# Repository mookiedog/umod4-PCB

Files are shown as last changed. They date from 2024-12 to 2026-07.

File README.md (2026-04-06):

# umod4-PCB

The Ultramod4 (A.K.A [umod4](https://github.com/mookiedog/umod4)) project is a real-time datalogger for Aprila Gen 1 ECUs.
It replaces the EPROM in an Aprila Gen 1 ECU with a circuit board that replaces the EPROM with a fast CPU that emulates an EPROM.
The EPROM emulation CPU's flash contains a special data logging firmware that the ECU will run.
The data-logging firmware is modified to send a real-time stream of ECU data to an interface on the umod4-PCB.
Software running in a daughterboard on the umod4-PCB combines the incoming ECU data stream with real-time GPS location and velocity information.
The combined data stream gets written to a logfile on a micro SD card.

The complete project is made up of:

* [umod4](https://github.com/mookiedog/umod4): the repository containing all the software that runs on the umod4-PCB.
* [UM4](https://github.com/mookiedog/umod4/tree/main/ecu/src): a special data logging firmware that runs inside the Gen1 ECU, currently resides inside the umod4 repository
* umod4-PCB: this repository, containing the PCB design files

The view below shows a top view of the 4V1a PCB, currently the most recent design.
The board's strange shape and cutout are mostly required to access ECU mounting points while avoiding interference with tall components on the ECU itself.
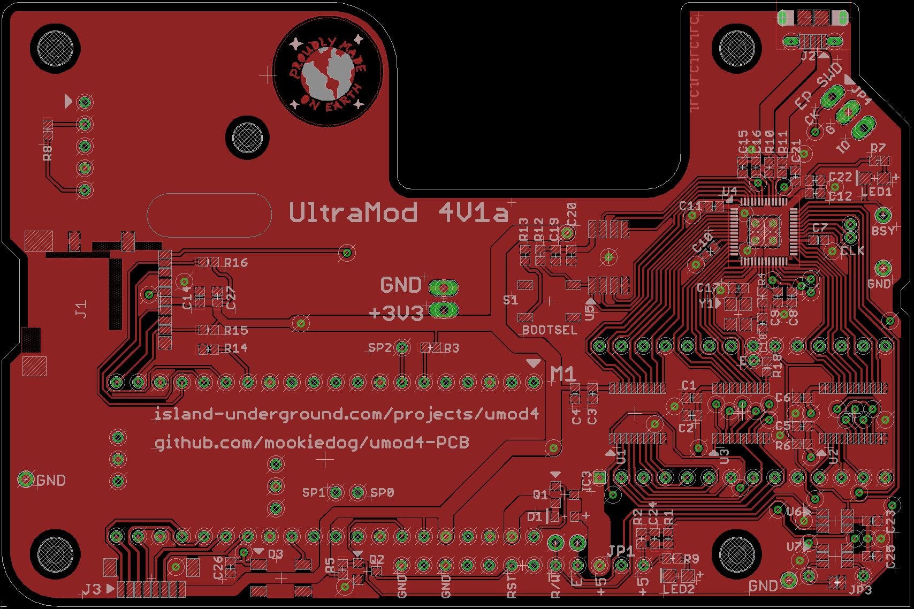
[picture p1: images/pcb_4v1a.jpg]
Ultramod 4V1a PCB layout


## PCB Status

The first version of the board (marked '4V0b' on its silkscreen) was fabricated at JCLPCB in 2022 and tested.
The second revision, the 4V1a board, was produced by JLCPCB in Jan 2025.
It incorporates all the workarounds from 4V0b, plus a number of changes and enhancements discovered over the last 18 months.
See the file [ChangeList.md](ChangeList.md) for the complete set of changes incorporated by 4V1.

The 4V1 version PCB has passed all its tests so far.

## Goals

### Design For Manufacture

This project uses a bare RP2040 chip to emulate the EPROM in a Gen 1 ECU.
The chip is too difficult for me to place by hand for reflowing the board using my [home-brew reflow](https://github.com/mookiedog/Reflow) process.
Instead, this PCB is designed for fabrication at JLCPCB.com.
Where possible, the BOM parts were chosen from JLCPCB's "basic" component list to avoid the fee for using an "extended" component.
Even so, stocks of "basic" parts fluctuate and components become obsolete, so the BOM might change with time to accomodate those changes.

Once any requirement for hand assembly was eliminated, the door was open to use smaller 0402 components on the PCB.

The initial version of the design (4V0b) has proven it can go end-to-end through the entire JCLPCB fabrication process where the resulting boards function as designed.

### Accessibility

I am not interested in making this project into a product that I would sell and support.
That said, it may be interesting enough for other Aprilia owners out there who have software and/or hardware skills that they might want to replicate the project for their own bike.

Who knows, it might be one of those things where a batch of boards gets made from time to time for people who are interested, feel like participating, and know that it is not a product.
Seriously, the last thing on earth that I want is someone sending me a note complaining that I haven't got WiFi working yet.

## Design Tool Choice

The project is currently developed using Cadsoft Eagle version 7.6, the last version I got years ago.
It's because I've used Eagle for the last bazillion years, and I own that old version outright.
These days, you are forced to forced to buy new versions of Eagle on a monthly subscription basis.
That doesn't work for me, because I make no money off this stuff and can't afford the subscription fees.
Too bad, I like Eagle.

I realize that at some point it would be worth switching the design over to something like KiCad to make it more accessible to the open source community.

Someday.

## Project Status

A ton of software exists, and a ton is left to write.

That said, the key to going for a ride though is that the fake EPROM on the circuit board needs to work. And it does!

Below, is a scope shot of the ECU performing memory cycles.
The top trace is the E clock generated by the ECU processor (a MC68HC11 variant).
The bottom trace is generated by the firmware that is pretending to be an EPROM.
The bottom trace goes high when the fake EPROM firmware reads the address and control signals from the HC11 memory bus.

If the memory cycle does not target the EPROM, the firmware drives the lower trace back to zero again very shortly after reading the address and control signal info.

If the memory cycle targets the EPROM with a read operation, the firmware takes a bit more time to access the proper memory byte corresponding to the desired EPROM memory byte, then drive that data onto the memory bus.
The lower scope trace gets driven low again to indicate the time that the read data is available on the memory bus.

Finally, if the memory cycle targets the EPROM with a write, the firmware is required to wait even longer for the write data to finally appear on the bus.
The fake EPROM firmware drives the lower trace back to zero to indicate the exact time that it samples the write data off the HC11 memory bus.

Given that all of these operations are going on all the time, the lower trace has been set up so that it shows examples of the three different operations (ignore, read, write) superimposed on each other:
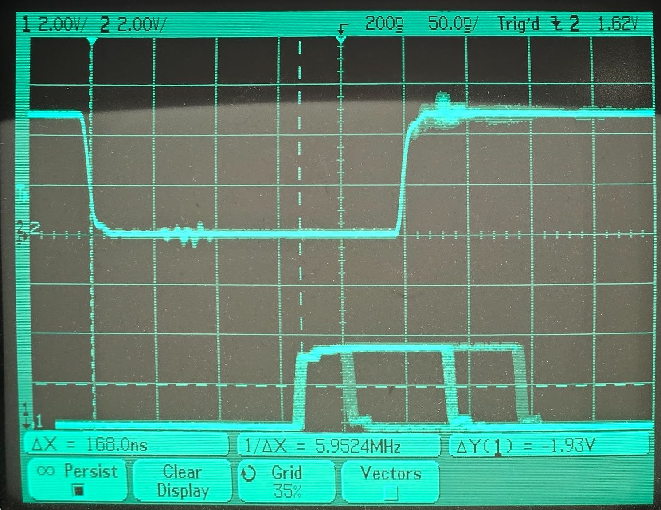
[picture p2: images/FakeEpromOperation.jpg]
Fake EPROM Operation


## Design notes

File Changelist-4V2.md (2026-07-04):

# Changelist Tracker for 4V2 PCB

## Dicking With Parts due to LCSC Supply Issues

* Changed the 100R resistors protecting SWD signals to be 0603 for availablity reasons
* Changed the E series resistor to be 100R/0603 to take advantage of above. AI indicates that 100R will be overdamped, but will be to my benefit at a slow 2 MHz clock.
* The 1K 0402 resistors R1, R4, R10 will be a minimum charge of $9. Changing the package does not help, and R1 needs to be 0402 anyway.
* The 470R resistors (R7,R11,R20,R21) can all be 0402 C25117 as per the 4V1
* The 4K7 R26 (SWD pullup) is converted to 0603
* Oddly, the GRN C2297 and YEL C2296 LEDs are basic parts, but the RED C2295 is an extended part. I think I will have the 470R resistors added for the SPARE3/4 LEDs, but the LEDs themselves left unstuffed.

## Outstanding 4V1a Issues

All known 4V1 issues have been resolved as below.

## GPIO Assignment Changes from 4V1 to 4V2

The SPARE1 and SPARE2 signals were used by the 4V1 software for various purposes.
The usage for these pins becomes official on the 4V2 PCB.

The LCD connector has been retired with 4V2 and the connector pins are assigned new functionality with 4V2.

| GP | 4V1 PCB Name | 4V2 PCB Name | Function |
| -- | --- | --- | --- |
| GP27 | SPARE0 | SPARE0_ADC | spare, renamed to reflect ADC capability |
| GP26 | SPARE1 | DISK_BSY | SD card disk activity and "hello" notification |
| GP5  | SPARE2 | EP_SWD_DIS | Disable WP control of EP SWD |
| GP16 | SPI0_MISO | SPARE3 | spare (footprint for LED exists) |
| GP17 | SPI0_CS | SPARE4 | spare (footprint for LED exists) |
| GP18 | SPI0_SCK  | SPARE5 | spare |
| GP19 | SPI0_MOSI | EN_VDD_SD | Enable SD card power |
| GP20 | SPI0_DC | VCCB_PWR | test if VCCB is present |
| GP21 | SPI0_BKLT | EP_BOOTSEL | can drive EP_BOOTSEL to '0' during EP RESET |

All other signals and their GPIO assignments remain the same:

* RP2040 U0_TX, U0_RX
* RP_SWCLK, RP_SWD
* EP_RUN
* GPS: PPS, TX, RX
* SD Card: !CARD, SCK, MOSI, MISO, DAT1, DAT2, CS
* WS2812: DI

## Changes Completed for 4V2

### Resolve Excessive Power Draw At ECU Power-Off

__Problem:__ The 4V1 board draws excessive current if the ECU is powered off while the umod4 remains powered from a USB supply. It would appear that the bus buffer behaves badly when VCCB is present without VCCA, in spite of what the Nexperia data sheet says. The RP2040 can end up driving the HC11 data bus into the bus transceiver, backpowering it.

__Change:__ There were 2 changes made to resolve this issue.

The first was a firmware change. Existing firmware would disable the read-cycle bus drivers at the start of the next E cycle. When power failed, the 'next' E cycle would never come, and drivers (if enabled) would remain enabled. To fix this, a PIO state machine was added to drive the read data. A failsafe PIO timer mechanism would unconditionally disable the bus drivers if the firmware failed to do so because the next E clock never came.

The PIO mechanism resolved the issue for 4V1 PCBs. For 4V2, an additional change has been made. The 4V1 required using a Nexperia 74LVC4245 because it purported to deal with the issues that arise when one bus was powered, but the other was not. However, it would appear that there were perhaps more subtleties resulting in the excessive current draw. To fully resolve the issue and allow other manufacturer's versions of the 74LVC4245 which were stated as being fussier with power sequencing, a new power supply was added so that the +5 and +3.3V supplies to the bus transceiver would both be derived from +5 ECU supply.

A [TLV757P](https://www.lcsc.com/product-detail/C485517.html) linear regulator was added to power all voltage translation ICs:

* Two 8-bit address buffers (U1, U3)
* 8-bit bidirectional data bus buffer (U2)
* U6 dual inverter

These ICs are now completely unpowered when +5_ECU is absent (ignition OFF). The supply is named VCCB, per the 74LVC4245 naming convention.

This is safe because:

* Address buffers and E signal are always inputs to the RP2040, with pulldowns activated. Losing power causes no issues.
* Inverted HC11 bus signals (W/!R and CE) are also input only to the RP2040, with pulldowns activated.
* The 74LVC4245 spec requires VCCB to be applied at the same time or after VCCA. Since the regulator creates VCCB from VCCA, the soft-start delay guarantees this ordering.
* EP firmware uses a failsafe PIO timer to stop driving the bus if VCCB power fails mid-cycle.

The TLV757P features active output discharge when not enabled, making VCCB_PWR detection reliable.

__Verification:__ With USB power only (no ECU), confirm VCCB is 0V and current draw matches pre-4V1 baseline (~130-160 mA). With ECU powered, confirm VCCB is 3.3V and VCCB_PWR GPIO reads '1'. Turn ECU off and confirm VCCB discharges quickly and VCCB_PWR reads '0'.

#### Testing on 2026-04-04

The PIO timer-based read cycle failsafe drive disable has been verified.

On the motorbike using old firmware that exhibits the issue:

1) power ECU via USB: current 130-160mA
2) ignition on: USB power drops to 40 mA
3) ignition off: USB power rises to 270 mA instead of the previous 130-160mA.

Tuono using new firmware that uses PIO to always disable bus writes:
1) power ECU via USB: current 130-160mA
2) ignition on: USB power drops to 40 mA
3) ignition off: USB power drops back to same current as before

### Delete U7 & 4V1 ECU Power Present Signal

__Problem:__ U7 (dual inverter used as +5V ECU power detector) is no longer needed now that the VCCB regulator provides a simpler way to detect ECU power.

__Change:__ Deleted U7. The WP now monitors ECU power via GPIO VCCB_PWR, a pullup direct to the VCCB regulator output. A logic '1' means the regulator is powered and operating. The active discharge feature ensures the signal drops to GND quickly when power is removed. This simplifies the board and frees up area.

__Verification:__ Covered by VCCB regulator verification above.

### Add Pullups to EP TX/RX Lines

__Problem:__ The EP TX line to the WP can float during reset or before UART initialization, potentially causing framing errors.

__Change:__ Added pullups to both the EP TX and RX lines to hold them at idle state.

__Verification:__ After EP reset, confirm TX and RX lines are at logic '1' before UART initialization. Confirm UART communication works normally after boot.

### Move Reset Control Circuitry

__Problem:__ The reset control components occupied space needed for indicator LEDs at the rear edge of the board where they are more easily visible under the rear seat.

__Change:__ Relocated the reset control circuitry to free up rear card edge space for LEDs.

__Verification:__ Visual inspection of layout. Confirm HC11 reset behavior is unchanged.

### Upgrade SPAREn Accessibility

__Problem:__ The SPARE0/1/2 pads were in locations that were difficult to access for probing or attaching jumper wires.

__Change:__ Moved SPAREn pads to be accessible from the card edges. Added test points for every SPAREn signal to make wire attachment easier.

__Verification:__ Visual inspection that pads are accessible from card edges. Confirm continuity from test points to their respective GPIOs.

### Add Monocolor LEDs to Some Spare Signals

__Problem:__ During development, it would be useful to have visual indicators on spare GPIO lines, but the 4V1 board had none.

__Change:__ Added LEDs to spare signals. This is trivial to do, costs basically nothing, and has proven useful in the past.

__Verification:__ Toggle spare GPIOs in firmware and confirm corresponding LEDs illuminate.

### Daisy Chain 1 More WS2812 LED for WP

__Problem:__ A single WS2812 LED limits the WP's ability to indicate multiple statuses (e.g., SD activity, EP status) simultaneously.

__Change:__ Added a second WS2812 in a daisy chain for the WP to drive. The LEDs are separated by a good distance to make them easy to distinguish at a glance. Usage (SD status, EP status, etc.) is yet to be determined.

__Verification:__ Drive both WS2812 LEDs with different colors from WP firmware and confirm both are independently controllable.

### Add Test Points for EP/WP Comms

__Problem:__ The existing test points up by the RP2040 had holes and spacing too small for general use with standard probes or jumper wires.

__Change:__ Added a new 0.1 inch pinheader to provide easier access to EP/WP communication signals.

__Verification:__ Confirm 0.1" header pins fit and signals are accessible with standard probes.

### Add a Test Pad for CPU DVDD 1.1V Supply

__Problem:__ No easy way to probe the RP2040 core voltage during bringup or debugging.

__Change:__ Added a test pad and silkscreen label near C15 for the CPU DVDD 1.1V supply.

__Verification:__ Measure DVDD at the test pad and confirm it reads ~1.1V when the RP2040 is powered and running.

### Add Power Control IC for SD Card

__Problem:__ SD cards can get into states where they need a power-cycle to recover. The 4V1 board has no way to cycle SD card power without removing the card.

__Change:__ Added a SY6280 high-side power switch (SOT23-5) controlled by EN_VDD_SD (GP19). The SY6280 actively discharges the load when disabled, ensuring a clean power cycle. The SOT23-5 package/pinout is shared by many alternative switches in case a replacement for the SY6280 is ever needed.

__Verification:__ Toggle EN_VDD_SD from WP firmware. Confirm SD card power drops to 0V when disabled (measure at card socket VDD). Confirm active discharge brings voltage down quickly. Confirm SD card initializes correctly after power is re-enabled.

### Add GPS Module Designator to Silkscreen

__Problem:__ The GPS module had no silkscreen marking on the 4V1 board, making it harder to identify during assembly or debugging.

__Change:__ Added GPS module designator to the silkscreen layer.

__Verification:__ Visual inspection of silkscreen.

### Make FET Q1 a "No Stuff"

__Problem:__ Q1 bypasses the Schottky diode drop on D1 when VBUS is absent, saving a small amount of power on the ECU supply. This optimization is not meaningful for a non-battery-powered device like the ECU.

__Change:__ Left the footprint for Q1 but marked it as "no stuff" in the BOM. If Q1 is ever needed, the FET can be hand-soldered after the fact.

__Verification:__ Confirm the board operates correctly with Q1 unpopulated. Measure voltage drop across D1 and confirm it is within acceptable limits for the ECU power budget.

### Add WP Control of EP BOOTSEL

__Problem:__ If the EP goes fully rogue, the WP has no way to force it into BOOTSEL mode for recovery without physical intervention.

__Change:__ Added an EP_BOOTSEL signal driven by the WP through a 1K series resistor. Combined with the existing 10K pullup, this forms a divider that pulls QSPI_SS to ~0.3V, well below the 0.8V logic '0' threshold. A testpoint via is also provided to allow a jumper wire to GND BOOTSEL through a 1K resistor as a last-resort manual override.

__Verification:__ With EP running normally, confirm QSPI_SS is high. Assert EP_BOOTSEL from WP while holding EP in reset, then release reset and confirm EP enters BOOTSEL mode. Also verify the testpoint via can force BOOTSEL with a jumper wire.

### Add Pullups/Pulldowns to EP SWD Bus

__Problem:__ EP reflash via SWD showed that the internal pullup on SWD data is insufficient. A scope probe's loading alone was enough to make SWD operation unreliable. Additionally, an undriven SWDCLK line can pick up noise and cause false clock edges.

__Change:__ Added a 4.7K pullup on SWD data (stronger than 10K, allows faster SWD bus operation). Added a 10K pulldown on SWDCLK per standard recommendations to prevent noise-induced false clocking.

__Verification:__ Perform EP SWD reflash via WP and confirm reliable operation. Attach a scope probe to SWD data and confirm operation remains stable. Confirm SWDCLK is low when idle.

### Add Series Resistors to EP SWD CK and IO

__Problem:__ The EP SWD pins are exposed when attaching an external debugger. The RPi documentation recommends series protection resistors.

__Change:__ Added 100R series resistors on the external debugger path only. The WP-to-EP SWD wiring remains a direct connection so that the WP can reflash the EP without the resistors degrading signal integrity.

__Verification:__ Attach an external SWD debugger to the EP (with EP_SWD_DIS grounded) and confirm reliable debug operation through the 100R resistors.

### Add Pullups to SD Card MISO and DAT3 Signals

__Problem:__ DAT1 and DAT2 already have pullups, but DAT0/MISO and DAT3/CS do not. The DAT3/CS pullup is critical: if DAT3 is not pulled high at power-up, the SD card will enter SPI mode, which can only be exited via power-cycle.

Note that this issue became a non-issue with the addition of power control of the SD card. By leaving the card powered off, it would give the WP time to drive appropriate GPIO pullup/pulldowns on the signals. That said, 10K resistors are essentially free, so this hardware solution has been added.

__Change:__ Added pullup resistors to:

* DAT0/MISO — probably harmless since it is master input, but resistors are cheap insurance
* DAT3/CS — critical pullup to prevent unintended SPI mode entry

__Verification:__ Power-cycle the SD card (via SY6280) and confirm the card initializes in 4-bit SD mode, not SPI mode. Measure DAT3 at power-up and confirm it is pulled high before the WP drives it.

### Add a 0.1" Jumper for EP_SWD_DIS

__Problem:__ The WP controls the EP SWD bus for reflashing. When an external debugger is attached to the EP, the WP must be prevented from driving the SWD lines or it will conflict with the debugger.

__Change:__ Added a 0.1" jumper header on EP_SWD_DIS (GP5). Installing a shorting plug or jumper wire to ground tells the WP that it must not drive the SWD connection to the EP.

__WARNING: EP_SWD_DIS must be grounded before connecting an external SWD debugger to the EP!__

__Verification:__ With jumper installed, confirm WP does not drive EP SWD lines. With jumper removed, confirm WP can reflash EP via SWD normally.

### Delete WP Ability to Drive HC11 RESET

__Problem:__ The original board design allowed either the WP or EP to assert HC11 RESET signal. This has been determined to be both not useful, and potentially problematic. The EP should be the ONLY device that controls HC11 RESET. A malfunctioning WP should not be able to accidentally assert HC11 RESET, preventing a rider from getting home home.

## Deferred from 4V2

The following features were considered, but deferred from the 4V2 implementation.

### Replace RP2040 with RP2354A

One problem that has been annoying to this point is that I would have really liked to add a WS2812 LED for status reporting, but there is no spare GPIO on the standard package.
The RP2350 is available in a larger package with more GPIO.

Upsides:

* The Hazard RISC-V core has 16 registers available for the fake EPROM code.
    Essentially doubling the number of general purpose CPU registers compared to the Cortex should make it easier to write more complicated versions of the fake EPROM, should additional features be required.
* The RP2354A has 2 megabytes of flash built into it.
    This would allow me to delete my own 16 megabyte SPI flash and decoupling cap.
    The smaller capacity should not be a huge problem.

Downsides:

* Swapping the package represents a very big change to hardware and software:
    * Rewriting the fake EPROM code in RISC-V would take some effort.
    The Cortex M33 is not really suitable for use in a cycle-counting firmware.
    * There is not a lot of spare real estate in that location on the PCB for a larger package.

Ultimately, it seems like way too much work to get a status LED.
The simpler solution might be to parallel the original DBG_BSY LED with a WS2812 and accept that both features will not be available at the same time.
See "Consider Adding WS2812 LED", below.

At the moment, the RP2040 is totally capable of doing everything it needs to do.
If future features require a faster processor, the RP2040 could be up-clocked from its current 125 MHz to as much as 200 MHz.
If the future required more RAM, then an RP2350 becomes more viable, at least in its small package.

At the moment, this feature seems unlikely to survive the cut.

### Consider Using 2mm WS2812C Parts

_I am going to skip this, at least this time.
The 5050 parts are easy to solder after the fact, and now there is room for 3 of them on the back edge with the revised layout.
If 2020 LED get too close together, they become hard to distinguish._

Last time I looked, JLCPCB was not real happy if I spec'd the smaller parts.
I believe the issue was that they felt they needed to bake the parts before soldering them, which I'm sure would be an annoying manual problem for them.
Since then: it appears that JLCPCB also wants to bake the 5050 parts.
This means that any WS2812 parts regardless of package need to be manually soldered after receiving assembled boards from JLCPCB.
If that's the case, there is no benefit in spec'ing 5050 parts.
The only remaining issue is whether or not the 2020 parts can be hand-soldered.
The 5050 parts are easy to hand solder.
The 2020 parts look more difficult to place, but given that the pads are castellated and have only 2 pads per side, it should be doable.

### Add EP-driven WS2812 for EP Status

Now that the WP can forward the EP RTT output all the way to a phone, the RTT output serves as a much better indication of problems than a status LED.

### Backup Power To Guarantee Completion of SD Writes

_The backup power issue has been resolved due to the addition of the LogStore class to drive LittleFS.
The LogStore write performance improvements have made the proposal to support FAT for performance reasons a complete non-issue._

LittleFS has some issues regarding the time to perform a write/sync operation as the SD card fills. One possible way to deal with that is to use something like FAT FS instead. However, FAT FS has its own terrible problems that random power cuts can destroy the integrity of the file system. But if LittleFS proves troublesome enough, it might be a consideration to move to FAT FS, but with a backup power system to guard against data corruption issues.

One possible method of dealing with unexpected power cuts (ignition key off events) would be to enable some sort of short-term power backup option before beginning a SD Card write, then turning the backup power off after the write completes.
If the power failed during the write, the backup source would ensure that the write completed.
After completing and disabling the backup power, the system power would fail immediately but the filesystem would not be corrupted.

* LiPo battery backup

    The little RC quadcoptor 50 mAH LiPo batteries should work fine to power the PicoW while it is doing a write operation for 1 second or so.

    Note: These connectors are advertised on Aliexpress and ebay as JST 1.25, but they are __not__ JST connectors, they are Molex Picoblade.

    Mating through-hole socket is part number 5304702XX, where XX=60 means gold plated.

    See [molex catalog](https://www.molex.com/content/dam/molex/molex-dot-com/en_us/pdf/datasheets/987651-3691.pdf?inline) for more info on Picoblade series.

### Need Bigger Drill for Keystone 4952 test points

Don't bother changing anything: just use the 1035 test points.

The Keystone 1035 test points fit OK with their current drill size.
The Keystone 4952 test points need a bigger hole than the 1035.
Check if the 4952 test point has the right size drill in the library.

### Verify GPS Hole Spacing

I'm not sure that the hole spacing is quite right.
It is close enough to force things to work, but it could be better.

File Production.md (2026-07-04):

# Production: Getting a Board to JLCPCB

## JLCPCB Parts: Basic vs Extended

JLCPCB's parts catalogue is at https://jlcpcb.com/parts — a subset of LCSC.com
available for their assembly service. Results show whether each part is Basic or
Extended. There is a filter checkbox to restrict to Basic parts only.

Basic parts carry no added setup fee. Extended parts incur a small fee per unique
part number. Prefer Basic where a suitable equivalent exists.

---

## Build directory

All generated files go into `build/`, which is gitignored. It has two subdirectories:

| Directory | Contents | Owner |
|---|---|---|
| `build/cam/` | Gerbers and drill file generated by the CAM processor | Eagle CAM |
| `build/jlcpcb/` | Everything that will get uploaded to JLCPCB, plus the HTML BOM | Script + ULP |

To start completely clean, delete `build/cam/` before running the CAM processor.
Eagle will recreate it. The script always regenerates `build/jlcpcb/` from scratch.

---

## Step 1 — Pre-flight Checks in Eagle

### Ratsnest

In the schematic editor: verify that there are no air wires.
A 'ratsnest' command must return "Nothing to do!"

### ERC

In the schematic editor: run the ERC. It should show only known/approved errors and
warnings.

### DRC

In the board editor: run the DRC. It should show only known/approved errors and
warnings.

The DRC only checks **visible** layers. Before running, make exactly these layers
visible and turn everything else off:

- Top, Bottom
- Pads, Vias, Unrouted
- Dimension
- tOrigins, bOrigins
- tNames, bNames
- tStop, bStop
- tKeepout, bKeepout
- tRestrict, bRestrict
- Drills, Holes, Milling

In particular make sure **tPlace** and **bPlace** are **off**. If they are on, they will
produce spurious "Stop Mask" errors from package outline geometry.

---

## Step 2 — Generate Gerbers (CAM Processor)

Open the CAM processor in Eagle and load the project's `.cam` file
(e.g. `jlcpcb_2_layer_v72.cam`). Click **Process Job**.

Warnings about polygons causing large plot data are harmless — click **Yes to All**
and continue. JLCPCB has no problem with the resulting files.

The CAM job writes 12 files to `build/cam/`:

| File | Contents |
|---|---|
| `<name>.GTL` | Top Copper |
| `<name>.GBL` | Bottom Copper |
| `<name>.GTO` | Top Silkscreen |
| `<name>.GBO` | Bottom Silkscreen |
| `<name>.GTP` | Top Solder Paste |
| `<name>.GBP` | Bottom Solder Paste |
| `<name>.GTS` | Top Solder Mask |
| `<name>.GBS` | Bottom Solder Mask |
| `<name>.GKO` | Board Outline / Slots |
| `<name>.XLN` | Drill Data (Excellon) |
| `<name>.gpi` | General Info (not sent to JLCPCB) |
| `<name>.dri` | Drill Info (not sent to JLCPCB) |

JLCPCB requires only the ten files with **uppercase** extensions.

---

## Step 3 — Run the Pre-Production Script

From the project root in WSL:

```
python3 preproduction.py
```

The script:

- **Checks** that all ten gerber/drill files in `build/cam/` are newer than both
  the schematic and board files. Reports stale files and tells you to re-run the
  CAM processor if needed.
- **Generates** `build/jlcpcb/<name>-bom.html` — a human-readable BOM with two
  sections: JLCPCB assembly parts and DNP / hand-solder / other parts. LCSC part
  numbers are clickable links to the JLCPCB component search page so you can verify
  availability and Basic vs Extended status before ordering.
- **Generates** `build/jlcpcb/bom.csv` — the BOM in JLCPCB upload format.
- **Generates** `build/jlcpcb/<name>_top_cpl.csv` — the centroid file, by invoking
  Eagle in batch mode with the modified `jlcpcb_smta_exporter_v7.ulp`.
- **Creates** `build/jlcpcb/<name>.zip` — the ten gerber/drill files ready for
  JLCPCB upload. Only created if the gerber check passes.

A clean run looks like:

```
============================================================
 Pre-Production Check: <name>  (2026-07-02 10:30)
============================================================
 [PASS] Gerbers are current
 [PASS] BOM: 22 PCBA parts, 14 other/DNP
 [PASS] CSV:  build/jlcpcb/bom.csv
 [PASS] HTML: build/jlcpcb/<name>-bom.html
 [PASS] CPL:  build/jlcpcb/<name>_top_cpl.csv
 [PASS] ZIP:  build/jlcpcb/<name>.zip (52 KB)
============================================================
```

Exit code is 0 on a clean run, 1 if anything requires attention.

**Note:** Every output file is overwritten each run. `build/jlcpcb/` is fully
reproducible — there is no user-authored content there that can be lost.

---

## Step 4 — Review the HTML BOM

Open `build/jlcpcb/<name>-bom.html` in a browser. Walk through the JLCPCB Assembly
section and click each part number link to confirm:

- The part is in stock at JLCPCB
- Basic vs Extended status matches expectations
- The part number still refers to the correct component

---

## Step 5 — Upload to JLCPCB and Review

Go to https://www.jlcpcb.com. Log in or create an account.

Click **Instant Quote**. Drag and drop `build/jlcpcb/<name>.zip` onto the Gerber
upload area and wait for JLCPCB to process the file.

Verify the board parameters match your design intent. Typical 2-layer settings:

| Parameter | Value |
|---|---|
| Base material | FR4 |
| Layers | 2 |
| Different Design | 1 |
| Delivery format | Single PCB |
| Thickness | 1.6 mm |
| PCB Color | Green |
| Silkscreen | White |
| Surface finish | HASL (with lead) |
| Copper weight | 1 oz |
| Via covering | Tented |
| Min hole size | 0.3 mm |
| Board Outline Tolerance | Regular |
| Confirm Production File | Yes |
| Mark on PCB | Order number (specify position) |
| Electrical Test | Flying probe fully test |
| Gold fingers | No |
| Castellated holes | No |
| Edge plating | No |

Enable the PCB assembly option and upload:
- `build/jlcpcb/bom.csv` — the BOM file
- `build/jlcpcb/<name>_top_cpl.csv` — the centroid file

If the preview or BOM review reveals a problem, fix it in Eagle, increment the
silkscreen version letter, and repeat from Step 2 (CAM).

---

## Step 6 — Place the Order and Tag the Release

Once you are satisfied with the JLCPCB preview and ready to place the order, tag
the current source state and create a GitHub Release to permanently record what
was submitted.

```bash
git tag -a 4v2c -m "First order — brief description of what changed from previous"
git push origin 4v2c
gh release create 4v2c build/jlcpcb/* \
  --title "umod4 4v2c" \
  --notes "First order. Fixed R3 designator position from 4v2b."
```

The `build/jlcpcb/*` glob attaches the zip, bom.csv, cpl.csv, and HTML BOM as
release assets — a permanent record of exactly what was sent to JLCPCB.

Then place the order.

---

## Parts Placement Review

After uploading the BOM and CPL, JLCPCB shows a placement viewer. In practice this
viewer frequently shows parts offset or with incorrect rotations — do not be alarmed.
Check the box to **verify parts placement before production** and proceed through the
purchase flow.

About an hour after you confirm the PCB order a JLCPCB engineer will manually review
the placement. They will send two images: the original placement as extracted from your
files, and their corrected version. Carefully verify their corrections match your
intent — in particular check that polarised parts (LEDs, diodes, electrolytics) have
the correct orientation.

JLCPCB engineers are generally reliable at catching and correcting placement issues.
If something is wrong with the PCB itself they will cancel the job and contact you
before proceeding.

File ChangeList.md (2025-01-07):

# Changelist for 4V1

## Version 4V1a PCB is Being Fabricated

The final 4V1a changes:

* Added an indicator LED to show when +5_ECU was present
* Added indicator marks for the LEDs on the board to aid in parts placement at JLCPCB
* Changed the WS2812 LED from a 2020 package back to the 5050 package.
JLCPCB said that the 2020 package was "difficult" for them to manage.
In contrast, the 5050 package is easy to hand solder.

As far as fabrication goes, the following parts will get hand soldered after receiving the boards:
* WS2812-5050
* Hirose SD Card holder

The SD card holders were out of stock.
The WS2812 5050 cannot be installed using the PCBA economic process because they need to be baked before installation.
Since both parts are JLCPCB extended parts, leaving them off saves $6 in extended parts fees.
The total cost at JCLPCB was just over $10 per board, including parts and assembly, not including shipping.

Captures problems and workarounds with the existing 4V0b PCB revisions. Identifies potential improvements for future revisions.

## Note: Power Supply Simplification

The power supply changes from the previous interim checkin have been deleted.
To get umod4 power and the resulting wifi connection, it turns out that a much simpler solution is to just use a USB extension cable that plugs into the Pico W.
If the extension cable gets plugged into a USB charger while parked, the umod4 will be active
while the rest of the ECU remains powered off.

## V4.0b Resolved Problems

The following issues were detected and resolved during bringup:

1) __HC11_RESET_IN circuitry is not permitting HC11 to run__

    Issue: ECU uses a pullup on HC11_RESET, but the voltage divider formed by R8/R9 is too much of a load to let HC11_RESET to go high enough to let the ECU run
    The HC11_RESET_IN feature is not usable, had minimal usefulness in the first place, and will be removed in the next version.

    Workaround: Remove R9.

1) __ECU can’t operate without SW running on a PicoW to enable the bus buffers via ADDR_EN__

    This was annoying during early development, and adds another point of failure if the WP/PicoW were to fail during operation.

    Workaround: Remove R17 and ground the resistor pad closest to the ‘7’ of the silkscreen ‘R17’.
    This permanently enables the bus driver instead of requiring that the PicoW must enable the bus buffers via software.

    The bus buffers will be enabled whenever the ECU +5V is present.

1) __EP RP2040 does not boot reliably__

    Issue: The specific crystal spec'd on the BOM does not start up as fast as the Pico bootrom expects.
    See [here](https://forums.raspberrypi.com/viewtopic.php?t=334143) for more information on the topic.

    Fix: No PCB fix is required. The umod4.h board file needs to define the following symbol:

            #define PICO_XOSC_STARTUP_DELAY_MULTIPLIER 64

1) __EP SWD Debugging does not work__

    Issue: The SWD CLK and DAT silkscreen was correct, but the wiring to the pins was swapped.

    Workaround: When attaching a debugger, swap the squid connections for SWD CLK and SWD DAT.

1) __GPS would disable UART during debug sessions__

    Fixed by adding a pullup resistor to the PicoW GPS TX pin to hold the TX pin high by default after RESET.
    A GPIO pullup controlled by firmware is not suitable because the debugger will not let firmware run after RESET.

    See below for more details.

## V4.1 Proposed Changes & Enhancements

Closed.

## V4.1 Implemented Changes, So Far

### Critical Changes

1) __Delete RESET_HC11_IN__

    The signal is not not necessary: the WP knows when EP is running because the EP will tell it so.

    Fix: Deleted the signal along with R8 and R9.

    Note: This fix frees up two more GPIOs for the WP.

1) __Fix wiring connections on SWD squid pins__

    CLK and DIO were swapped but the silkscreen was correct.

    Fix: Fix silksreen, also moved the silkscreen up a bit to be more visible.

1) __ADDR_EN should not be driven by PicoW__

    Reasoning: Bike should run even if PicoW is dead or missing.

    Fix: R17 has been removed and the ADDR_EN signal permanently grounded.

1) __GPS Disables UART During Debug Sessions__

    It turns out that a NEO-8 GPS will disable its UART interface if it sees too many framing errors on its RX pin within 1 second.
    This can happen if the RX pin is held to '0' for some reason.
    This should not be a problem in a real system, but while debugging, when the system is stopped at the initial breakpoint in main(), the RX pin will be at '0' until the system boots enough to init the serial interface to its idle state of '1'.

    Fix: Added a 10K pullup to the UART0_TX signal that drives the GPS RX pin

### V4.1 Changes and Enhancements

1) __Added Indicator LED for +5_ECU__

    An indicator light was added to show when +5 ECU power is present.
    This light would be off when the umod4 is powered from a USB cable attached to the Pico board and it would be on whenever the ignition key is on.

1) __Allow For SD Card Access Using 4-bit SPI Mode__

    The 4V0 PCB accessed the SD card using the 1-bit SPI mode subset built into all SD cards.
    The 4V0 wiring scheme used the R2040 SPI1 silicon unit to perform SPI transfers.
    It could have also used a PIO program to perform the transfers, but using the silicon block works just fine.

    The 4V1 board adds additional wiring to allow for 4-bit IO to the SD Card using PIO libraries that can be found on the web.
    The 4-bit mode should greatly increase the transfer rate from the SD card when uploading log files via WiFi.

    The wiring has been added in a fashion that allows the SD card to be accessed via 1-bit mode and using silicon SPI unit #1, or in 4-bit mode via PIO.
    A requirement of the PIO code is that DAT0 through DAT3 must occupy 4 consecutive GP pins where DAT0 is the lowest numbered GP pin of the four.

    If for some reason, the 4-bit PIO code cannot be made to work, 1-bit SPI mode will work as before.

    The table below shows how the wiring will be done so that the SD card can be accessed via RP2040 hardware SPI unit #1, as well as a PIO implementation of 4-bit mode:

| GP | SPI Unit 1 | SD Card in 1-Bit SPI Mode | SD Card in 4-Bit Mode |
|--|--|--|--|
| GP10 | SCK | CLK | CLK |
| GP11 | TX | CMD/MOSI | CMD |
| GP12 | RX | MISO | DAT0 |
| GP13 | N/A | N/A | DAT1 |
| GP14 | N/A | N/A | DAT2 |
| GP15 | N/A | CS | DAT3 |

1) __Changed C27 Part Number__

    The previous part number C368809 is a JCLPCB extended part.
    The new part number C23733 is still a Samsung capacitor 4.7 uF, 10V, X5R but is available as a JCLPCB basic part.

1) __Changed DBG_BSY LED Package__

    The package for the LED connected to DBG_BSY was changed from 0603 to 0805.
    The original 0603 LED is not available anymore.
    The selection of basic LED parts is quite limited.
    The only emerald green LED available as a basic part comes in an 0805 package: [C2297](https://jlcpcb.com/partdetail/Hubei_KentoElec-KT0805G/C2297).

1) __Swapped Pico W End-for-End__

    This change allows a mini USB cable be plugged into the Pico W even with the ECU lid attached.
    The other end of the USB cable can be plugged into a standard 5V USB charger while the bike is parked.
    When connected to a charger, the Pico W and its WiFi connection will be active even when the key is off.

    This change had the happy side effect of making the wiring flow much simpler by getting the LCD and SD Card closer to SPI pins after swapping their SPI units.
    The LCD is now driven by SPI0 and the SD Card by SPI1.
    It also made sense to swap the GPS Uart and the RP2040 Uart connections at the same time, for the same reasons.
    The GPS now uses UART 1, and the RP2040 serial connection uses UART 0.

    Other connections got moved around.
    The umod4 software will need to be updated for the pin changes.

1) __RP_RUN signal was renamed EP_RUN__

    This happened at some point in the past, just documenting the change here.

1) __RP2040: Made HC11 RESET Control Permanent__

    Under normal circumstances, the RP2040 should be the only thing controlling HC11 RESET.
    This has the benefit that an ECU with a malfunctioning Pico W would still be rideable as long as the RP2040 was able to boot.

    Note that the HC11 RESET signal *can* still be controlled by PicoW software, but it is expected that the PicoW would only do that under exceptional circumstances.
    For example, if the PicoW was to use the SWD debug interface to reflash the RP2040, the PicoW would want to assert HC11 RESET before taking control of the RP2040 via the debug unit.

    1. Get rid of the solder jumper option
    1. Moved the GND test point to where the old SPARE testpoint was located

1) __Deleted SWD debug access via J3 & J4__

    J3 and J4 were 4-pin JST connectors that connected to RP2040 and PicoW debug ports.
    A decision was made that squid pins are fine, especially in conjunction with the Raspberry Pi debugger unit.

    1. Do not stuff squid pins during assembly - they can easily be added after the fact.
    Normal users will not need them, only SW developers.

1) __Added a Real Footprint for EP SWD Squid Pins__

    The original squid pin connections were just vias on the board, carefully named & placed.
    They are now a real 1x3 pinheader.

1) __WS2812 Moved for Better Visibility__

    Moved the package to the front edge of the PCB for better visibility.
    As mentioned earlier, the 5050 package is still being used because JCLPCB says that the 2020 package is 'difficult' for them.
    The 5050 package cannot be sent through the economic PCB assembly service because it needs to be baked.
    These LEDs will be hand soldered.

1) __Add squid pins for J3/WP for use with PicoProbe__

1) __Add a test point to scope the buffered E signal__

    Scoping this signal was beneficial during bringup so a testpoint would make it easier.

    1. Added a 0.028 via as a test point.
    The size 0.028 matches the DIP socket and is large enought to not be tented.

1) __Add a test point for EP GPIO24/TX so that it can be used to measure RP2040 CLKOUT__

    Having access to CLKOUT was useful during bringup.

    1. Used a 0.028 via so it would not be tented. Also made the corresponding RX uart signal the same drill size so both signals could be scoped at these test points
    1. I'm not bothering with adding a test pad for the PicoW because a scope can attach directly to the GPIO24 pin if desired.

1) __HC11 XTAL hole needs to move to the left and be as tall as possible__

    The crystal is not in a particularly fixed location according to my collection of ECUs.
    There is benefit in making the XTAL hole a bit bigger to tolerate placement issues.

    1. Moved the left side of the hole to add an additional 0.050 inch.
    1. Increased the hole size by 0.010 on top and bottom

1) __GPS mounting hole does not line up very well__

    The problem was the drawing did not spec the distance between the solder holes and the mounting hole.
    Measuring the real parts added about 0.7mm to the distance from the original footprint.
    Note that fixing this required rotating the board so that the cable heads off towards
    the ignition transistors.
    It was either that, or make the board slightly taller.

1) __Delete S2__

    Never used. Since it is an analog pin, it is probably better reserved for future use.

1) __Flipped JST Socket J5 (The auxiliary/LCD SPI port)__

    This makes it way easier to hand solder if anyone wants to add it.

1) __Make decoupling capacitance match SD card spec__

    As defined in the SD card spec specification 3.01, section E.2: use a 4.7uF cap followed by a 0.1 uF cap.

1) __Moved HC11 reset control parts from under the Pico W__

    This allows the module to be soldered down without a socket, although it seems unlikely that this would happen.
    For example, the Pico W could be replaced with a Pico 2 W (or whatever comes after that) if the module is socketed.

1) __More clearance for mainboard capacitor by the GND test point near JP4__

    Made a small notch in the side to allow for the capacitor a bit of extra room.

1) __Added TP2 GND Testpoint__

   Somehow, TP2 GND testpoint got left off the original PCB.
   Bringup confirmed that it would be handy to have one on the lower right for attaching scope probes.

## Deferred Changes

These changes might be reconsidered in the future, but are not going to be included on the next revision.

1) __Replace the MicroSD socket with something more modern from LCSC__

    The current Hirose DM3AT-SF-PEJ was used because I had some in stock and could hand solder it after getting the board back from JLCPCB.
    That Hisrose part is just barely available from LCSC, but it is available from Digikey in great quantity.
    If JLCPCB runs out of them, I can always get them from Digikey and then hand solder them.

    The main issue with designing in a new part is that the footprints are all unique, complicated, and weird.
    My Hirose footprint is a known quantity and works great.

1) __Add the ability to power-control the SD card__

    During testing, I have seen cards that fail spectacularly after bad commands to the point that they need a power-cycle to continue. It would also make the whole hot-plug thing a bit safer because the hotPlug manager would keep power off while a socket was empty, only powering it up after a card had been inserted for some amount of time. It should only need a logic-level PFET to implement it.

    1) There are lots of commodity USB power switch controllers that would do perfectly. They are logic-level controlled, have ESD protection, surge management, etc and cost 10 cents at LCSC.

1) __Add a WS2812 to the EP RP2040__

    Use color patterns to indicate things like boot/run/flash-in-progress/ECU-heartbeat.

    This might be handy, but is slightly troublesome:

    1. The WS2812 needs to be on a regular GPIO so that it can be driven by PIO.
    It would either require sharing a pin for DBG_BSY and WS2812 DI, or I would need to move DBG_BSY to a QSPI pin like SCK.

## Discarded Changes

The following changes were under consideration, but discarded for various reasons.

1) __Series termination resistor on E is not required__

    It makes the signal a bit cleaner, but the ADDR signals are not much worse.

    Determination: The resistor is essentially free and everything works, so I'm leaving it alone.

1) __Add 10-pin debug header for WP__

    Determination: Not required.

    Use a cheap, standard Raspberry Pi debug unit and attach it using the squid pins built right on top of the PicoW.

    The 10-pin connector was convenient if using a Segger J-Link debug unit, but the RPi debugger is cheaper and much easier to source.

1) __Power Measurements__
    1) __Add ability to measure SD Card Current Draw__
    1) __Add ability to measure total 3V3 consumption__
    1) __Add ability to measure VSYS current__

    Determination: I can't measure 3.3V accurately anyway because it will not reflect the 3.3V consumed by the PicoW itself.
    I already know that modern SD cards consume almost nothing at idle.
    The GPS power is interesting, but I can easily get just that because it is on a connector.
    It might be nice to measure VSYS, but I can pretty much calculate it from the input supply and assume an 80% to 90% efficient power conversion process.

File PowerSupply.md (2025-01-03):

# Umod4 Power Supply

This doc is for capturing thoughts about how the umod4 should be powered.

In the big picture, there are really just two situations:

1) Normal operation: ECU and umod4 both power on and off with the key

2) Data transfer mode: key off, but umod4 gets powered while ECU remains unpowered

The point of data transfer mode is to allow the umod4 board wifi access with the bike turned off and parked. This mode allows logs to be uploaded or OTA firmware updates to be performed.

The simplest way to do this is to attach a USB power cable to the PicoW VBUS pin and snake it out
of the ECU to a location where a rider could plug in a USB charger, much as they might also connect
a battery charger after a ride.

The more complicated solution adds a power supply to the umod4 that is connected to the motorbike
battery. The umod4 could detect when the engine stops and remain powered for a while, or perhaps
even remain powered for as long as it detects a charger connected to the battery.

## Outstanding Questions

1. How much current can a JST connector take?

   Answer: the SR/SZ 1mm pitch JST connectors are rated at 700 mA.

It would be simplest if the USB power connector used a 2-pin JST connector like LiIon batteries use.
That connector should be able to fit through one of the 4 holes already present in the ECU lid.

## Current Plan

The simplest solution would be to just add a USB power port on an extension cable soldered to the umod4 board.
It is not a big hardship to attach USB power to the bike after parking.

As of now, I have a power supply designed and in place, but I don't need to stuff it with parts.
I could just add a could of pads that would allow me to attach a USB cable to the PCB.
It would probably be best to cut the umod4 end of the cable off and just solder the wires to the PCB.

Getting the wire out of the ECU will be an issue in either case.

## Design Requirements
The Umod4 power supply is designed to support a number of use cases:

  1. Software development and testing
      1. Bench testing of a bare Umod4 PCB board, not plugged into an ECU
          1. Power to be supplied via the PicoW USB connector
      1. Bench testing of a Umod4 PCB installed in an ECU
          1. Power could be supplied via PicoW USB connector
          1. Power could be supplied via ECU +5
              1. ECU needs +12 on its B+ pin
  1. General usage on a motorbike
      1. Power to be supplied via a fused, unswitched supply connected directly to the motorbike battery
          1. If the ignition is ON, the Umod4 is always powered
          1. If the ignition is OFF, and the Umod4 detects that the battery is on a battery charger, the Umod4 will remain powered so that it can respond to WiFi/Bluetooth control
          1. If the ignition is OFF and the Umod4 is not on a charger, it will remain powered for as long as it takes to download ride logs to a server and then power itself off.

Note1 : The system _could_ be installed on a motorbike without connecting the unswitched supply to the battery. This is **NOT** recommended. Under these circumstances, whenever the ignition is turned OFF, the Umod4 will be powered off immediately without allowing it to shut down gracefully. Abrupt shutdown events can cause corruption of the SD Flash memory.

Note 2: When bench-testing in an ECU, if no USB power is supplied, the Umod4 will take its power from the ECU 5V supply. This is not a huge problem in that the ECU power supply appears to be over-designed and can handle the extra load, but to avoid stressing the ECU 5V supply in any way, a USB power supply is recommended during test and development on a bench.

## Outstanding Issues
The real question is whether or not the selected voltage regulator can supply the 5V requirements of the Pico W, which is also powering the entire Umod4 board. In theory, 600 mA at 5V output is 3W available to the Pico W. If the PicoW can convert power at 90% efficiency, that would correspond to 2.7W of power at 3.3V. That is 800 mA of current at 3.3V.

With my current setup (GPS, flash card idling, LEDs on, PicoW not doing any wireless activity), plugging in the USB power reduces power supply current to the ECU by less than 90 mA. Since the ECU is a linear supply, it means that the Umod4 must be drawing no more than 90 mA.

## Background
The Pico W has an [RT6154](https://www.richtek.com/assets/product_file/RT6154A=RT6154B/DS6154AB-03.pdf) switchmode power supply. The ASIC is capable of supplying 3A when it is generating 3.3V from a 5V input.

The Umod4 board combines a pair of 5V sources (USB or ECU 5V on the 4V0 design) that feeds the Pico W VSYS input. The power combiner prioritizes the USB source of +5. If the USB +5 exists, it disables the 5V source from the 12V unswitched supply. This means that a Umod 4 board can be powered permanently by plugging in a USB cable, even if the Umod4 is inserted in an unpowered ECU.

The RT6154 converts the 5V VSYS supply to the 3.3V output used by the Pico W.  In addition to its own 3.3V power requirements, the Pico W is capable of supplying up to 300 mA to power the Umod4 board.

In the 4V1 power supply, the USB 5V input remains strictly for bench testing. If 5V USB is present, the Umod4 will remain powered permanently. The other power source is a +12 unswitched supply that generates 5V. That +5 output would replace the 5V_ECU input.

## Power Requirements
The potentially biggest power consumer looks like the SD card. It is a transient power requirement though only when accessing flash, especially when erasing or writing flash. If we were writing 10K bytes/sec, that would be 20 writes per second, or 50 mSec per write. They don't take that long to write, so the average power consumption would be a lot less than 163 mA.

The Umod4 hardware being powered by the Pico W would be:
* 67 mA Neo8 GPS
* 80 mA Micro SD (various manufacturers), this is a total worst case guess
* 50 mA RP2040 and serial flash
* 15 mA DS2812C LED

If everything except the Micro SD totals 130 mA, that leaves 170 mA for the Micro SD card. There is [some data](https://electronics.stackexchange.com/questions/33472/how-much-current-does-a-microsd-card-use) to indicate that when operating in SPI mode at the default 25 MHz, a card is limited to .36W at 3.3V, or 163 mA. That would seem to be right where we need to be.

### GPS
The Neo-8 data sheet says to size the power supply for a max draw of 67 mA. My measurements show that it draws between 44mA and 54mA during normal operation. I do not know how much power the active antenna is taking.

### Micro SD Card
Crude card measurements follow:

#### Samsung 32G
  1) Reads take about 500 uSec, power increases by 20 mA

  1) Writes take about 900 uSec, power increases by 40 mA

#### Netac 64G
  1) Reads take about 380 uSec, power increases by 20 mA

  1) Writes take about 900 uSec, power increases by 30 mA

#### Transcend 128G
  1) Reads take about 320 uSec, power increases by 20 mA

  1) Writes take about 1200 uSec, power increases by 30 mA.  That's slow but still over 300K bytes/sec.

### EP RP2040
I measured the RP2040 power consumption at about 25 mA when servicing HC11 memory requests. The W25Q128 SPI flash indicates that its worst-case power consumption is 25 mA max. Max power occurs during programming or erasing.

### DS2812C
I'm not sure what the actual power requirement is. The spec sheet says 5 mA, but I'm not clear if that is 5 mA total, or 5 mA per color, so 15 mA total. The ASIC itself draws 0.6 mA.

## Version 4V0

As is, the Umod4 is powered by 5V_ECU. The 5V_ECU supply is present when the ignition key is ON, derived from the B+ (nominal 12V) supply into the ECU. This also means that the ECU 5V supply is responsible for powering the entire Umod4 board, which has not-insignificant power requirements due to the GPS, the EP RP2040, the micro SD, and of course, the PicoW running WiFi.

The drawback is that when the ignition is switched OFF, power is unexpectedly cut off to the Umod4 which could be in the middle of a disk write.

## Proposed 4V1

The Umod4 power supply has a number of design considerations. Even though the Umod4 lives inside the ECU, it may be powered when the ECU is not powered. This allows for use cases like arriving home from a ride. The Umod4 would remain running after the ignition key is turned off so that it could dump ride logs to a server on the wifi network. Once all logs were dumped, and some time after the last user interaction with the Umod4 user interface, the Umod4 will power itself down.

The Umod4 will detect if it is attached to a battery charger, even if it was powered down when the charger was connected. As long as the system is on a charger, the Umod4 will keep its wifi connection alive. This allows a user to do things like push a Umod4 firmware update from inside the house knowing that the Umod4 will be powered out in the garage.

For development and testing, it needs to operate on a bench in situations where the ECU itself may or may not be powered. In operation, the power supply operates outside of the ignition key control. The basic idea is that if the ignition key ever turns on, the Umod4 comes to life. When the ignition key turns off, the ECU will power down immediately, but the Umod4 will remain powered until it decides to power down.

The Umod4 never needs to know what is happening on B+. The 5V_ECU power supply is derived from the B+ supply by ECU power supply circuitry, so if 5V_ECU is present, it means that B+ is present.

## Battery Charger Detection
The ECU needs to know what is happening on 12V_UNSW. The Umod4 power supply is derived from 12V_UNSW. The Umod4 needs to know if the voltage on 12V_UNSW rises enough to indicate that there is a battery charger present.

For any sort of active solution, I need a power supply. The power supply could be as simple as a voltage divider of perhaps divide by 4. This would mean that a part that could handle as much as 6V on its input would tolerate 24V on 12V_UNSW.

I would need a reset chip that is powered from the 12V_UNSW supply through the voltage divider. It really would be best if the chip only drew a few uA. When the supply rose to a point indicating that a charger was present, reset would be allowed to go HIGH, perhaps after a delay.

## Powering for Bench Testing
Bench testing is most easily accomplished with an ECU connector cut from an old wiring harness. The nominal +12V arrives on the B+ pin, and GND is supplied via the E01/E02/E03 pins. Without access to an ECU connector, it is also easy to solder wires directly to the B+ and E0x pins inside the ECU before they attach to the PCB.

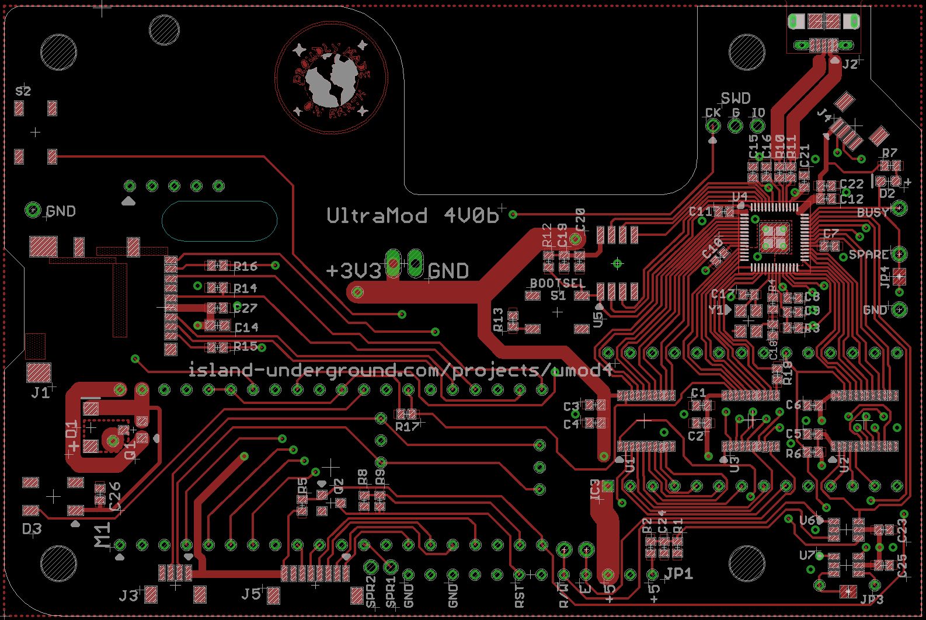
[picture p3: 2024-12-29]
images/pcb_image_4V0b.jpg

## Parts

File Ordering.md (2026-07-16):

# Ordering From JCLPCB

## Basic Parts Versus Extended

JLCPCB has its own website for parts at https://jlcpcb.com/parts.
That website represents the subset of parts at LCSC.com which are available for use with JLCPCB's assembly service.
When the parts come up after searching, they will indicate whether they are basic or not.
There is also a filter checkbox that restricts the results to basic parts.

## Fabrication Process

### ERC Check

In the schematic editor, run the ERC check. It should only have approved errors and warnings.

### DRC Check

In the board editor, run the DRC check. It should only have approved errors and warnings.

Note that the DRC check __only checks visible layers__. Before running the DRC, make sure that only the following layers are visible:

* Top
* Bottom
* Pads
* Vias
* Unrouted
* Dimension
* tOrigins, bOrigins
* tNames, bNames
* tStop, bStop
* tKeepout, bKeepout
* tRestrict, bRestrict
* Drills
* Holes
* Milling

In particular, make sure that the __tPlace__ and __bPlace__ layers are turned __off__.
If not, there will be a million "Stop Mask" errors where the package outline drawings interfere with the features we really care about.

### CAM Job Processing

Start off by making sure that any old production files are deleted.
Navigate to the main umod4 directory.
Delete all the files inside the 'output' directory.
Do not delete the output directory though.

Start the CAM processor.
Open the file jlcpcb_2_layer_v72.cam located in the main umod4 directory.
This cam file is identical to the jlcpcb cam file except that it sends all the output files to the 'output' directory.

Click the 'Process Job" button.
It will pop up a warning:

    "Package 'AMPHENOL_10118194-0001LF' of element 'J2' contains a polygon that may cause extremely large plot data.
    Continue?"

That is the USB connector where I got a footprint off the web.
The footprint works fine, but for whatever reason, it generates a big data file.
JLCPCB has no problem with it though, so click "Yes to all" to continue.

### Zip File Creation

Once the CAM job completes, there will be a bunch of new files in the main directory.
The cam file creates them according to JCLPCB's naming convention:

* umod4.GBL __Bottom Copper Layer__
* umod4.GBO __Bottom Silkscreen Layer__
* umod4.GBP __Bottom Solder Paste Layer__
* umod4.GBS __Bottom Solder Mask Layer__
* umod4.GKO __Board Outline (also includes internal slots, if any)__
* umod4.GTL __Top Copper Layer__
* umod4.GTO __Top Silkscreen Layer__
* umod4.GTP __Top Solder Paste Layer__
* umod4.GTS __Top Solder Mask Layer__
* umod4.XLN __Drill data file in Excellon format__
* umod4.gpi __General Information__
* umod4.dri __Drill Information__

The only files that JCLPCB needs are the 10 files with the uppercase extensions.
The .gpi and .dri files are strictly informational and not used by the fabrication process.

Create a zip file that contains all 10 files with the uppercase extensions.
Give it a name corresponding to the exact version of the umod4 board, such as umod4v1a.zip.
The zip file is the file that gets sent to JCLPCB. It contains everything required to make the bare printed circuit board.

## BOM and Centroid File Creation

The BOM and centroid files are required for the fabrication process after the PCB itself gets made.

The BOM file is the "Bill of Materials".
It defines what parts are required to fabricate the board.

The centroid file explains where each part listed in the BOM should be placed on the PCB, as well as how to rotate each part after removing it from the parts reel in the pick and place machine before placing it on the PCB.

From the board editor, select 'file/run ULP'. Select 'jlcpcb_smta_exporter_v7.ulp'.

A dialog window will come up.
Make sure you are exporting the Top layer.
Check the checkbox to indicate that you want to skip any part with a missing value.

Click 'OK'.

A save window will pop up asking for a directory to save the files to.
Select the 'output' directory inside the main umod4 directory, then click 'select directory'.

Navigate to the output directory.
There should be two new files:

* umod4_top_bom.csv
* umod4_top_cpl.csv

Verify that the timestamp on these two files match the time they were created, a few seconds ago.
If not, delete those two files, and try again.
Make sure that you do not have either of those excel files open in excel or the export operation silently fails!

Once the bom and cpl files are created properly, you can open them with excel.
If you open the bom file, you will see all the parts. The comment field contains things like the value of a resistor or capacitor, or maybe the generic part number for other things like connectors or ICs.
The most important thing is the column LCSC Part #.
A blank in this column means that the part is _not_ going to be installed as part of the fabrication process.
This may be desirable, if the part is optional for example.

## Triple Check Time!

1) Verify that the timestamp on the uppercase extension files generated by the CAM job are __all__ after the save time on the original schematic and board files

1) Verify that the timestamp on the zip file is after all of the files with the uppercase extensions

1) Verify that the timestamp on the bom and cpl csv files are after the zip file.

## Order At JCLPCB

Use a browser to go to https://www.jlcpcb.com.

If you don't have an account, make one.

Click "Instant Quote".
Drag and drop your zip file containing the PCB design files onto the quote page where it says 'add gerber files'.
It takes a few minutes for jlcpcb to process the zip file.

Verify:
* base material: FR4
* Layers: 2
* Different Design: 1
* Delivery format: Single PCB
* Thickness: 1.6mm
* PCB Color: green
* Silkscreen: White
* Surface finish: HASL (with lead)
* Copper weight: 1 oz
* Via covering: tented
* Min hole size: 0.3mm
* Board Outline Tolerance: Regular
* Confirm Production File: Yes
* Mark on PCB: order number (specify position)
* Electrical Test: Flying probe fully test
* Gold fingers: no
* Castellated holes: no
* Edge plating: no

...and so on.

## Parts Placement Issues

As part of the assembly purchase process, you need to upload your BOM and CPL files.
As soon as you have done that, a file viewer pops up that shows you how your parts will mount on the board.
In theory, all the parts should be drawn exactly where you wanted them, all with the proper rotations.
In practice, this viewer never, *ever* works right for me.
My 4V1 board showed every single part offset by about a quarter of an inch to the left.
In addition, the part rotations were wrong for a significant number of my parts.
It is disconcerting, but the key to success is to check the box that says you want to verify the parts placement before going into production.
With that box checked, keep going through the purchase process.
Another weird thing is that you have to OK the PCB for fabrication before you get a chance to OK the parts placement.
This means that your PCB is in their production queue before the parts placement gets worked out, which could get problematic if there were an issue with the PCB.

But maybe an hour after you OK the PCB and it is in process, you will get another note from a JCLPCB engineer.
You need to back to your order page and click some buttons to see what is going on.
The engineer will have manually checked everything to see how the parts should go on the board.
They will send you two pictures.
One picture shows the 'original' parts placement, before they make any changes.
The second picture shows the changes they have manually made to come up with what they think is the corrected parts placement.
You need to carefully examine the pictures and verify that the results are what you want.

Below, are are the before and after pictures I got from them regarding my 4V1 board.

Interestingly, the 'before' picture (immediately below) is not showing the horizonal offset for all the components like it did on the order webpage.
But clearly, you can see that the orientations are messed up on a few components:
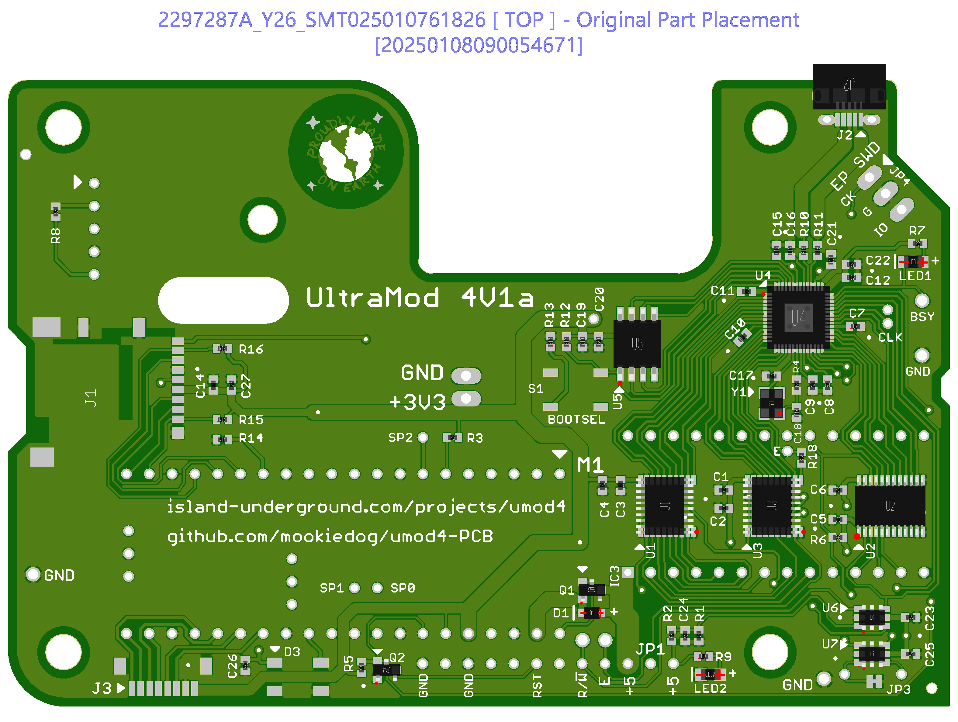
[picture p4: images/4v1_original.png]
Ultramod 4V1a PCB layout (before)


The red dots mark where JCLPCB believes pin 1 to be located.
Y1, U1, U3, U6, U7, Q1, and Q2 have improper orientations.

Here is the showing the parts placement after being processed by the engineer:
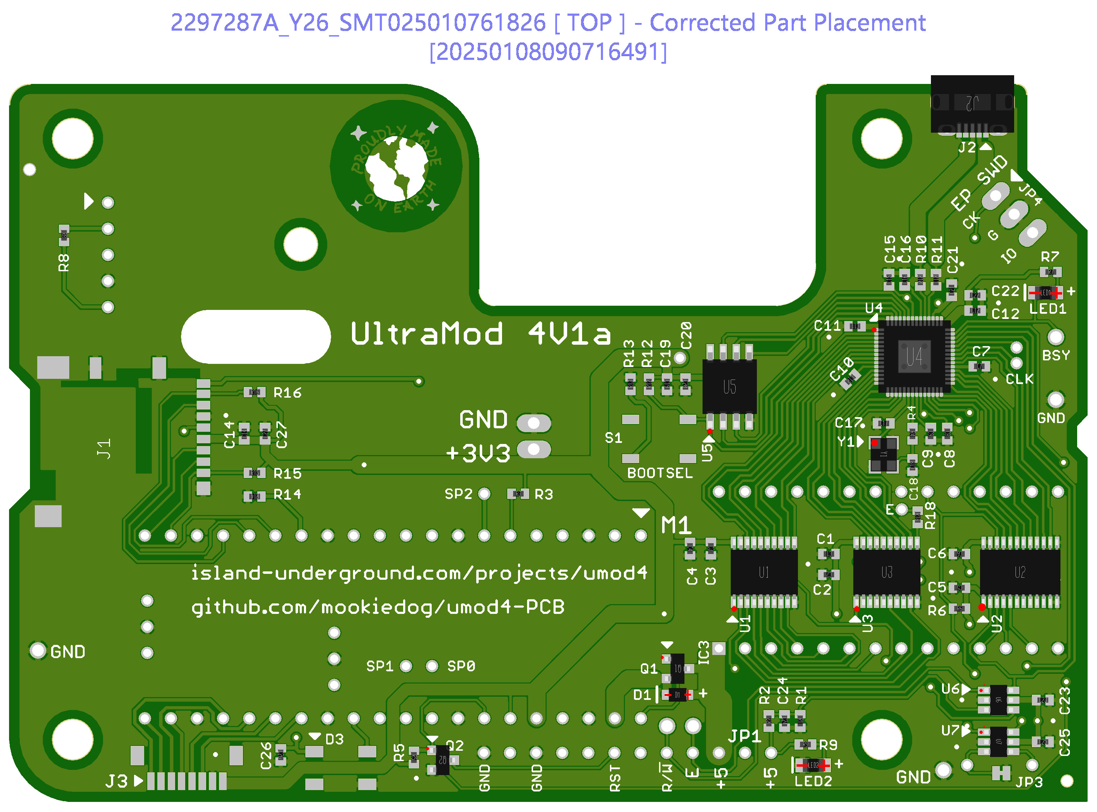
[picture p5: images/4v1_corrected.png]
Ultramod 4V1a PCB layout (corrected)


Now all the red dots line up with my white pin 1 indicators on the board's silkscreen.
The last thing is to make sure that polarized parts like the LEDs have their + and - connections to the proper ends.
In this case, everything looked fine so I told them to go ahead with production.

It has been my experience that the JCLPCB engineers do a good job at getting the placement correct for production.
The only problems I have had is with orientation of WS2812 LEDs.
The WS2812's manufacturer made an extremely unfortunate choice to mark pin 3 on their part with a triangle instead of pin 1 like basically everything else in the entire universe.
Next time, I will try marking VCC with a '+' and GND with a '-' on the silkscreen to see if that helps.

One other time, the JLCPCB engineer found an error on my board where I used the wrong package footprint for one of my parts.
They cancelled the job, I fixed the footprint, resubmitted and everything was fine the second time around.
But is sure is disconcerting to submit payment for boards that look so messed up at the time you order them.

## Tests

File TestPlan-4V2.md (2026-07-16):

# Test Plan: 4V2 Bring-Up

Bench bring-up checklist for boards returned from JLCPCB. Ordered so that risk is
retired before power is applied, and full power before firmware, and firmware
before the ECU is trusted with a board.

Background/rationale for each item lives in [Changelist-4V2.md](Changelist-4V2.md)
and [Verification.md](Verification.md) — this document is the executable checklist,
those are the "why."

## Equipment Needed

- Bench PSU with adjustable current limit (for B+ / 12V input)
- USB cable/power source for PicoW VBUS
- DMM
- Oscilloscope
- ECU test harness or bare wires for B+ / E0x (GND)
- SWD debugger (for external-debug-path tests)
- Several SD cards of different brands/sizes (see [PowerSupply.md](PowerSupply.md) for brands previously tested)
- Jumper wires for JP3, TP4

---

## 1. Incoming Inspection (no power applied)

- [ ] Populated/DNP parts match the BOM. In particular confirm **Q1 is unstuffed**
      (intentional "No Stuff" per 4V2 — [Changelist-4V2.md](Changelist-4V2.md#make-fet-q1-a-no-stuff))
- [ ] Polarized parts (LEDs, WS2812s, diodes) oriented correctly — cross-check
      against JLCPCB's post-order placement confirmation images
- [ ] GPS module designator silkscreen present and matches actual GPS placement
- [ ] DVDD 1.1V test pad silkscreen label present near C15
- [ ] TP4 (BOOTSEL disaster-recovery pad) present
- [ ] JP3 (EP_SWD_DIS 0.1" jumper) present
- [ ] New 0.1" WP/EP comms header present
- [ ] SPAREn test points present and appear accessible from card edges

## 2. No-Power Continuity Checks

- [ ] Resistance GND→rail on VBUS, VSYS, VCCB, +3.3V (WP), +3.3V (EP), VDD_SD,
      VLED — confirm no shorts before applying any power
- [ ] Continuity from each SPAREn test point to its corresponding GPIO (table below)
- [ ] Continuity from new EP/WP comms header pins to their signals

| GP | 4V2 Name | Test Point |
| -- | --- | --- |
| GP27 | SPARE0_ADC | yes |
| GP26 | DISK_BSY | yes |
| GP5  | EP_SWD_DIS | JP3 |
| GP16 | SPARE3 (yellow LED) | yes |
| GP17 | SPARE4 (red LED) | yes |
| GP18 | SPARE5 | yes |
| GP19 | EN_VDD_SD | — |
| GP20 | VCCB_PWR | — |
| GP21 | EP_BOOTSEL | — |
| — | RESET_HC_11 (old SPARE6) | testpoint only, WP no longer drives |

## 3. Power-Up Sequencing (current-limited PSU, no SD card inserted)

### 3.1 USB only (VBUS present, B+ absent)

- [ ] VSYS present, correct diode-drop relationship to VBUS
- [ ] VCCB = 0V (no B+ present)
- [ ] VCCB_PWR GPIO reads '0'
- [ ] DVDD test pad ≈ 1.1V once RP2040 is running

### 3.2 B+ only (12V via bench PSU, no USB)

- [ ] +5_ECU present, VSYS one diode drop below it
- [ ] VCCB ramps to 3.3V, VCCB_PWR GPIO reads '1'
- [ ] VLED ≈ 4.2V (2 Schottky drops off VSYS — must clear WS2812 3.7V min and
      RP2040 Vih margin)
- [ ] DVDD test pad ≈ 1.1V

### 3.3 Both sources present

- [ ] USB source takes priority per power-combiner design (no unexpected VSYS dip
      or glitch when B+ is applied second, or removed first)

### 3.4 ECU-off current draw — the headline regression test for this revision

This is the bug the whole VCCB regulator redesign exists to fix — treat it as the
pass/fail gate for the release, ideally reproduced on an actual bike/ECU per the
2026-04-04 baseline in [Changelist-4V2.md](Changelist-4V2.md#testing-on-2026-04-04):

- [ ] USB power only, ECU off: baseline current ~130-160 mA
- [ ] Ignition on (B+ applied): current drops to ~40 mA
- [ ] Ignition off (B+ removed, USB still powered): current returns to the
      ~130-160 mA baseline — **must not** rise to ~270 mA as it did pre-fix on 4V1
- [ ] VCCB discharges quickly on B+ removal (active-discharge feature of the
      TLV757P), VCCB_PWR reads '0' promptly

## 4. Firmware / SWD Bring-Up

- [ ] Flash WP firmware via USB/BOOTSEL
- [ ] With JP3 open, WP flashes EP firmware over SWD successfully
- [ ] With JP3 grounded, external SWD debugger attaches to EP through the 100R
      series resistors and operates reliably (confirms WP is NOT driving the bus)
- [ ] Idle SWD bus state (nothing attached, JP3 open): SWDCLK low, SWD data high
- [ ] EP_BOOTSEL: assert from WP while holding EP in reset, release, confirm EP
      enters BOOTSEL
- [ ] TP4 manual jumper-to-GND also forces BOOTSEL (last-resort path)
- [ ] EP TX/RX lines read logic '1' at idle before UART init; UART comms normal
      after boot

## 5. GPIO / Indicator Functional Tests

- [ ] Toggle SPARE3 (yellow) and SPARE4 (red) from firmware, confirm LEDs light
- [ ] Toggle SPARE5, SPARE0_ADC, SPARE6_ADC, confirm correct level at test point
- [ ] Drive both daisy-chained WS2812 LEDs independently with different colors;
      confirm chain order matches physical position on board
- [ ] Confirm WP has no path to drive RESET_HC_11 (net-level check — this signal
      is EP-only as of 4V2)
- [ ] HC11 reset behavior unchanged after reset-circuit relocation (functional
      reset test, not just visual layout check)

## 6. SD Card Subsystem

- [ ] At power-up, before firmware drives EN_VDD_SD, VDD_SD measures 0V at the
      card socket (power defaults off)
- [ ] Drive EN_VDD_SD high, confirm VDD_SD ramps and card enumerates in 4-bit SD
      mode (not SPI mode) — validates DAT3 pullup
- [ ] Toggle EN_VDD_SD off, confirm active-discharge brings VDD_SD to 0V quickly
- [ ] Re-enable and confirm card reinitializes cleanly (power-cycle recovery is
      the point of the SY6280)
- [ ] Repeat across multiple SD card brands/sizes for compatibility

## 7. GPS

- [ ] GPS acquires and produces PPS/TX/RX data as on 4V1 (unchanged GPIOs)
- [ ] Confirm connector/hole spacing is workable in practice (flagged as a soft
      concern in [Changelist-4V2.md](Changelist-4V2.md#verify-gps-hole-spacing))

## 8. Integration Test in ECU

- [ ] Install in ECU, connect B+/GND harness, USB, GPS antenna, SD card
- [ ] Fake-EPROM operation confirmed on scope per the E-clock/read/write trace
      method in [README.md](README.md)
- [ ] End-to-end datalogging pipeline (ECU stream + GPS + SD write) matches 4V1
      behavior
- [ ] Re-check known 4V1 bring-up issues do not reappear (see
      [ChangeList.md](ChangeList.md) "V4.0b Resolved Problems"): EP RP2040 boot
      reliability (confirm firmware still sets `PICO_XOSC_STARTUP_DELAY_MULTIPLIER`)
- [ ] Repeat the §3.4 ECU-off current-draw test on the actual bike as the final
      confirmation

## 9. Sign-off

- [ ] All items above pass
- [ ] Results recorded with date in [Changelist-4V2.md](Changelist-4V2.md)
- [ ] Any deviations documented and triaged (fab defect vs. design issue vs. new
      4V3 changelist item)

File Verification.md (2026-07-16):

# Verification Checklist

## New Parts

### TLV75733

The bus transceiver gets its own 3.3V VCCB power supply derived from +5_ECU. This means that the bus transceiver will only be powered when the ECU is powered. It eliminates the possibility of backpowering the ECU if VCCB is present, but VCCA is not.

* Pinout checked
* Cap sizing checked
* GND checked

TEST RESULTS:

* LED lights when VCCB is present
* When plugging into a powered supply (instant ON), the powerup rise time seems a bit slow (200 uSec). Regardless, the VCCB 3.3V output lags 5V slightly, which is the desired sequence for powering the bus tranceiver.
* Powerdown has correct sequence too: 3.3V falls at same rate as 5V

### VLED

Derived from VSYS, where VSYS is always 1 diode drop from +5_ECU or VBUS.
THis means that VLED is 2 Schottky drops from nominal +5V, or about 0.8V, so VLED will be 4.2V.
This is well above the min spec of 3.7V for the WS2812.
In addition, Vih (min) will be 0.7 * 4.2V, or 2.94V, well within the ability of the RP2350 to drive it to 3.3V.

TEST RESULTS:

* VLED is 4.5V, which is a bit higher than expected, probably due to low Vf at very low current draw and 5.1V VSYS. RP2350 needs to drive it to 3.15V to meet the Vh (Min) spec. That is close to the 3.3V VDDio voltage level, but in spec. The old system powered VLED at 5.1V with a Vh of 3.57V (Min), which violated the official spec.

### New RGB LED #2

TEST RESULTS:

* Works. Inits to OFF, can be set to various colors without affecting LED #1

### SY6280 High-Side Switch for SD Power

* 20 uF of capacitance on input, as per data sheet.
* EN default is GND, meaning 'OFF'. WP will need to drive EN_VDD_SD to '1' to power the SD card.

R16 is the ISET pin.
The value 10K was chosen because it is common on the board. It works out to approximately 0.68A current limit, which is not really useful for this application, but better than nothing.

TEST RESULTS:

* ENABLE/DISABLE works
* When enabling power, the input does not ring above 3.3V so the input capacitance must be sufficient
* ISET not tested (current limit is too high to be useful anyway)

### EP BOOTSEL

* The button was replaced by TP4, a pad that can be shorted to GND with a jumper wire. This is a disaster recovery feature, never to be used.

* EP_BOOTSEL was added as a signal driven by the WP that pulls BOOTSEL to GND through a 1K resistor.
It forms a resistor divider that will pull bootsel to about 0.5V, plently low enough to be a logic '0'.

TEST RESULTS:

* BOOTSEL measured at 0.32V when asserted by WP. This is well under 0.8V Vil limit.

### EP External SWD Pin Protection

As per RPi doc, 100R resistors were added (R1/R2) to protect the RP2040 from electrical transients that might show up on the squid pin wiring.

The WP drives the signals directly without going through the 100R resistors.

TEST RESULTS:

* WP can drive the EP SWD to reflash it
* Debug unit is able to drive the EP after WP SWD disable jumper is inserted

### EP SWD Resistors

R3/R4 were added to put the SWD pins in a known state at all times. Clock is pulled to GND, Data is pulled up via 4K7 resistor.

TEST RESULTS:

* Pullup/pulldown are present, do not cause any trouble, and the WP debugging of EP via SWD interface continues to function

### RESET_HC_11 disconnected from WP

This signal is only allowed to be driven by the EP from now on.
The WP never used it before, so no big deal.

TEST RESULTS:

* Tested by design: the connection was removed from the schematic

### JP3 0.1 Jumper Pins Added

This allows a developer to easily short EP_SWD_DIS to GND. This tells the WP to NOT use the SWD interface so that an external debugger can be attached to the EP.

TEST RESULTS:

* Works, detected by WP firmware

### 10K Pullups on GP0/1 (EP 32-bit TX, FLOW)

Again, these were not totally required, but 10K resistors are totally cheap and just solve the problem.

### SPAREn Pins

SPARE0 renamed to SPARE0_ADC, drives a testpoint
SPARE1 is officially DISK_BSY, which it always was after the bodge LED was added to all 4V1 boards (WORKS)
SPARE2 is officially EP_BOOTSEL, which it always was in 4V1 firmware
SPARE3 drives a yellow LED and a testpoint (WORKS)
SPARE4 drives a red LED and a testpoint (WORKS)
SPARE5 drives a testpoint
SPARE6_ADC is the old RESET_HC_11 signal, not used by WP anymore, drives a testpoint

GP20 is now VCCB_PWR, tied to VCCB through a pullup for VCCB power detection (NOT TESTED)
GP21 is the EP_BOOTSEL driver (TESTED, works: pulls BOOTSEL down to 0.32V)

### SD Card Pullups

Pullups were added so that all 4 DATn signals have pullups now.

### SD Card Powered by VDD_SD

The SD card is powered by the new high-side switch.
Default is OFF.
Drive VDD_SD_EN to '1' to power the SD card.

TEST RESULTS:

* power control works

## No Stuff Parts

### Q1: +5_ECU FET to VSYS

## Deleted Parts

### Old U7 is removed

+5 ECU power detection is now performed via resistor pullup to VCCB to a WP GPIO.

### EP USB Connector & 27R Resitors Removed

The WP control of the EP via SWD works perfectly.
The connector is expensive and just not required anymore.

The WP now has the ability to drive EP BOOTSEL, EP RESET, and the SWD interface. These mechanisms mean that the WP is always able to take control of the EP and install new firmware.

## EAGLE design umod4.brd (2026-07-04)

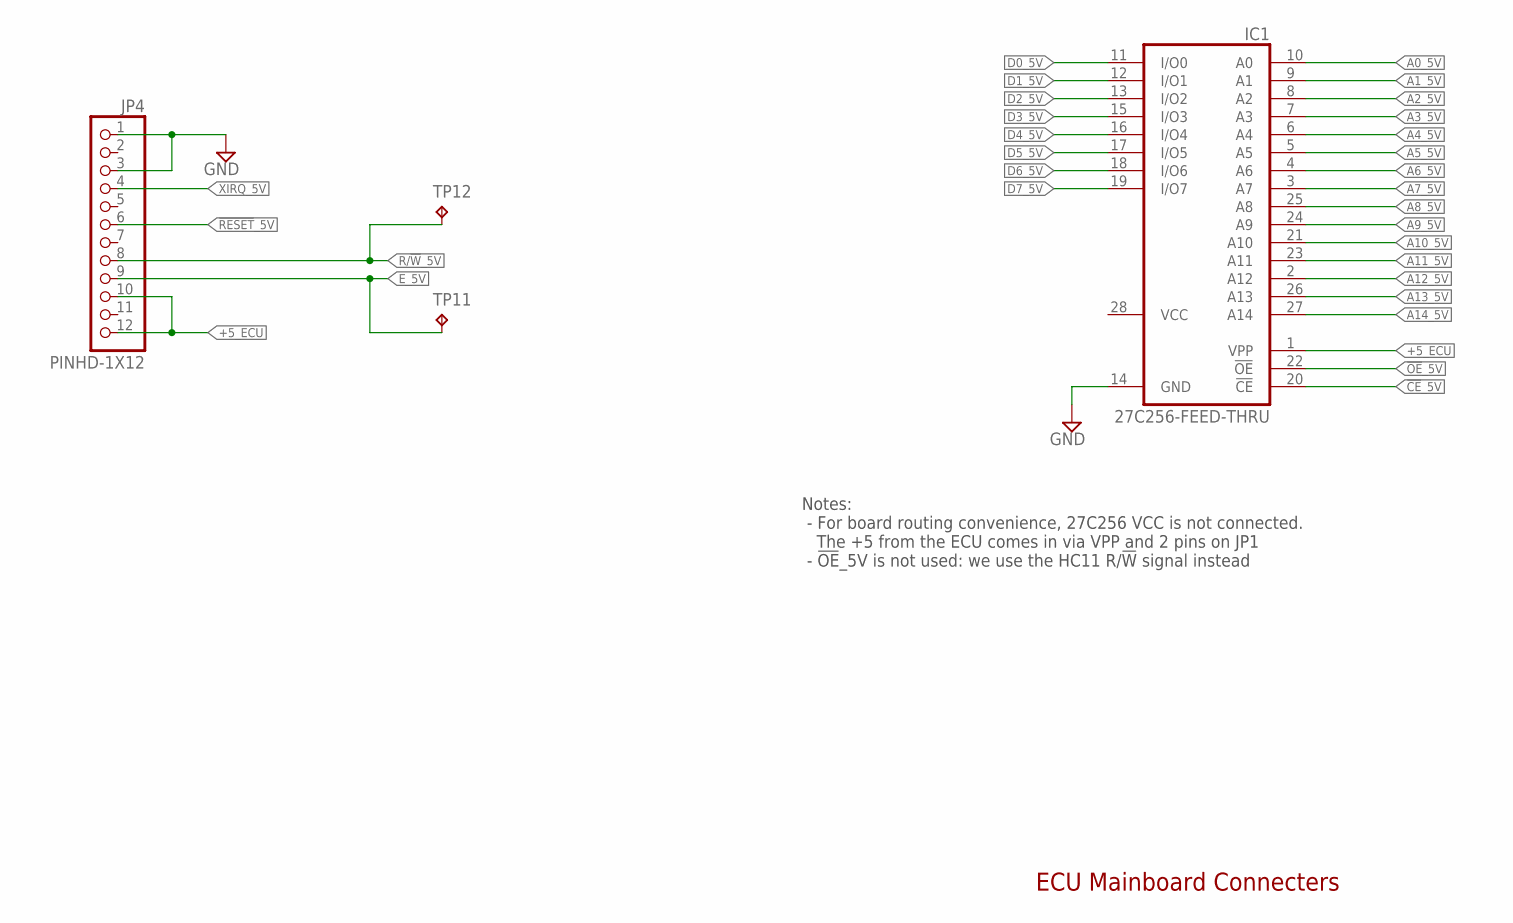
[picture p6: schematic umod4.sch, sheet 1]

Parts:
IC1: 27C256-FEED-THRU; DIL28-6
JP4: PINHD-1X12; 1X12
TP11, TP12: 1035; KEYSTONE-1035

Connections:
!CE!_5V: IC1.20 (!CE); also elsewhere on the board
!OE!_5V: IC1.22 (!OE)
!RESET!_5V: JP4.6; also elsewhere on the board
+5_ECU: IC1.1 (VPP), JP4.10, JP4.12; also elsewhere on the board
A0_5V: IC1.10 (A0); also elsewhere on the board
A1_5V: IC1.9 (A1); also elsewhere on the board
A2_5V: IC1.8 (A2); also elsewhere on the board
A3_5V: IC1.7 (A3); also elsewhere on the board
A4_5V: IC1.6 (A4); also elsewhere on the board
A5_5V: IC1.5 (A5); also elsewhere on the board
A6_5V: IC1.4 (A6); also elsewhere on the board
A7_5V: IC1.3 (A7); also elsewhere on the board
A8_5V: IC1.25 (A8); also elsewhere on the board
A9_5V: IC1.24 (A9); also elsewhere on the board
A10_5V: IC1.21 (A10); also elsewhere on the board
A11_5V: IC1.23 (A11); also elsewhere on the board
A12_5V: IC1.2 (A12); also elsewhere on the board
A13_5V: IC1.26 (A13); also elsewhere on the board
A14_5V: IC1.27 (A14); also elsewhere on the board
D0_5V: IC1.11 (I/O0); also elsewhere on the board
D1_5V: IC1.12 (I/O1); also elsewhere on the board
D2_5V: IC1.13 (I/O2); also elsewhere on the board
D3_5V: IC1.15 (I/O3); also elsewhere on the board
D4_5V: IC1.16 (I/O4); also elsewhere on the board
D5_5V: IC1.17 (I/O5); also elsewhere on the board
D6_5V: IC1.18 (I/O6); also elsewhere on the board
D7_5V: IC1.19 (I/O7); also elsewhere on the board
E_5V: JP4.9, TP11.P$1; also elsewhere on the board
GND: IC1.14 (GND), JP4.1, JP4.3; also elsewhere on the board
R/!W!_5V: JP4.8, TP12.P$1; also elsewhere on the board
VCC: IC1.28 (VCC)
XIRQ_5V: JP4.4

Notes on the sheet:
ECU Mainboard Connecters
Notes: - For board routing convenience, 27C256 VCC is not connected. The +5 from the ECU comes in via VPP and 2 pins on JP1 - !OE!_5V is not used: we use the HC11 R/!W! signal instead

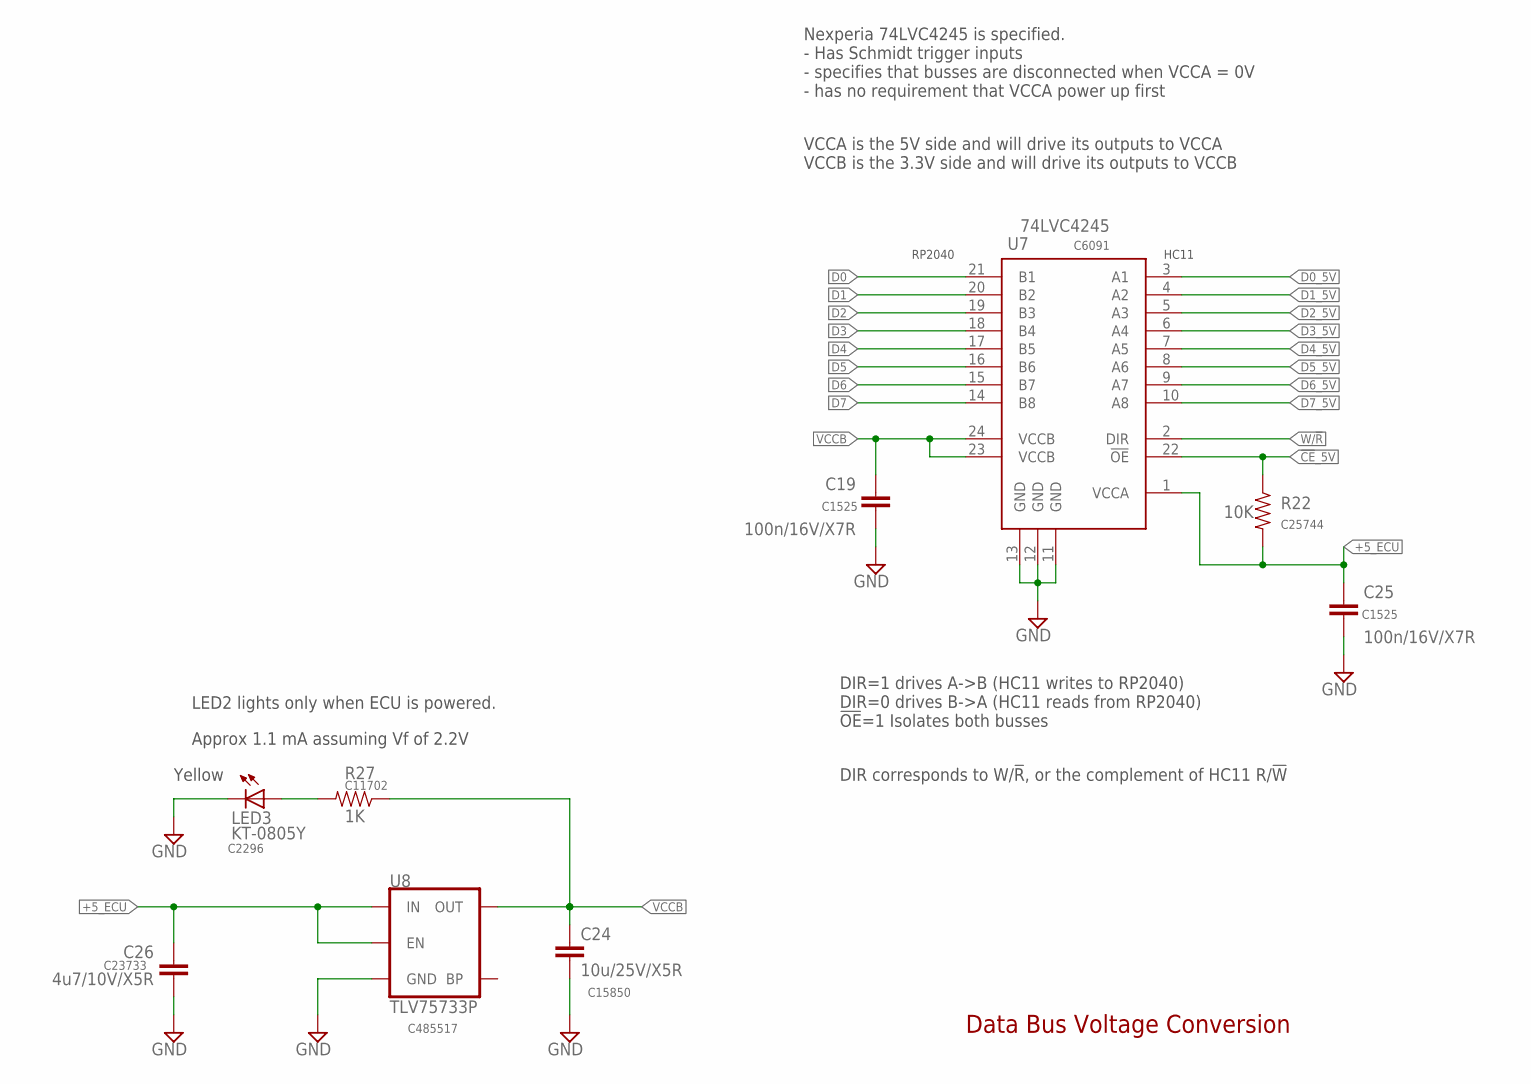
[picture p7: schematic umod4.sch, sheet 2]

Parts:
C19, C25: 100n/16V/X7R; 0402-CAP; LCSC_PART C1525
C24: 10u/25V/X5R; SMD-0805; LCSC_PART C15850
C26: 4u7/10V/X5R; 0402-CAP; LCSC_PART C23733
LED3: KT-0805Y; SML0805; LCSC_PART C2296
R22: 10K; 0402-RES; LCSC_PART C25744
R27: 1K; 0402-RES; LCSC_PART C11702
U7: 74LVC4245; TSSOP-24; LCSC_PART C6091
U8: TLV75733P; SOT23-5; LCSC_PART C485517

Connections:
!CE!_5V: R22.1, U7.22 (!OE); also elsewhere on the board
+5_ECU: C25.1, C26.1, R22.2, U7.1 (VCCA), U8.1 (IN), U8.3 (EN); also elsewhere on the board
D0: U7.21 (B1); also elsewhere on the board
D0_5V: U7.3 (A1); also elsewhere on the board
D1: U7.20 (B2); also elsewhere on the board
D1_5V: U7.4 (A2); also elsewhere on the board
D2: U7.19 (B3); also elsewhere on the board
D2_5V: U7.5 (A3); also elsewhere on the board
D3: U7.18 (B4); also elsewhere on the board
D3_5V: U7.6 (A4); also elsewhere on the board
D4: U7.17 (B5); also elsewhere on the board
D4_5V: U7.7 (A5); also elsewhere on the board
D5: U7.16 (B6); also elsewhere on the board
D5_5V: U7.8 (A6); also elsewhere on the board
D6: U7.15 (B7); also elsewhere on the board
D6_5V: U7.9 (A7); also elsewhere on the board
D7: U7.14 (B8); also elsewhere on the board
D7_5V: U7.10 (A8); also elsewhere on the board
GND: C19.2, C24.2, C25.2, C26.2, LED3.C, U7.11 (GND), U7.12 (GND), U7.13 (GND), U8.2 (GND); also elsewhere on the board
unnamed: LED3.A, R27.2
VCCB: C19.1, C24.1, R27.1, U7.23 (VCCB), U7.24 (VCCB), U8.5 (OUT); also elsewhere on the board
W/!R!: U7.2 (DIR); also elsewhere on the board

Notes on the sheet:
Data Bus Voltage Conversion
DIR=1 drives A->B (HC11 writes to RP2040) DIR=0 drives B->A (HC11 reads from RP2040) !OE!=1 Isolates both busses
VCCA is the 5V side and will drive its outputs to VCCA VCCB is the 3.3V side and will drive its outputs to VCCB
DIR corresponds to W/!R!, or the complement of HC11 R/!W!
RP2040
HC11
Nexperia 74LVC4245 is specified. - Has Schmidt trigger inputs - specifies that busses are disconnected when VCCA = 0V - has no requirement that VCCA power up first
Yellow
Approx 1.1 mA assuming Vf of 2.2V
LED2 lights only when ECU is powered.

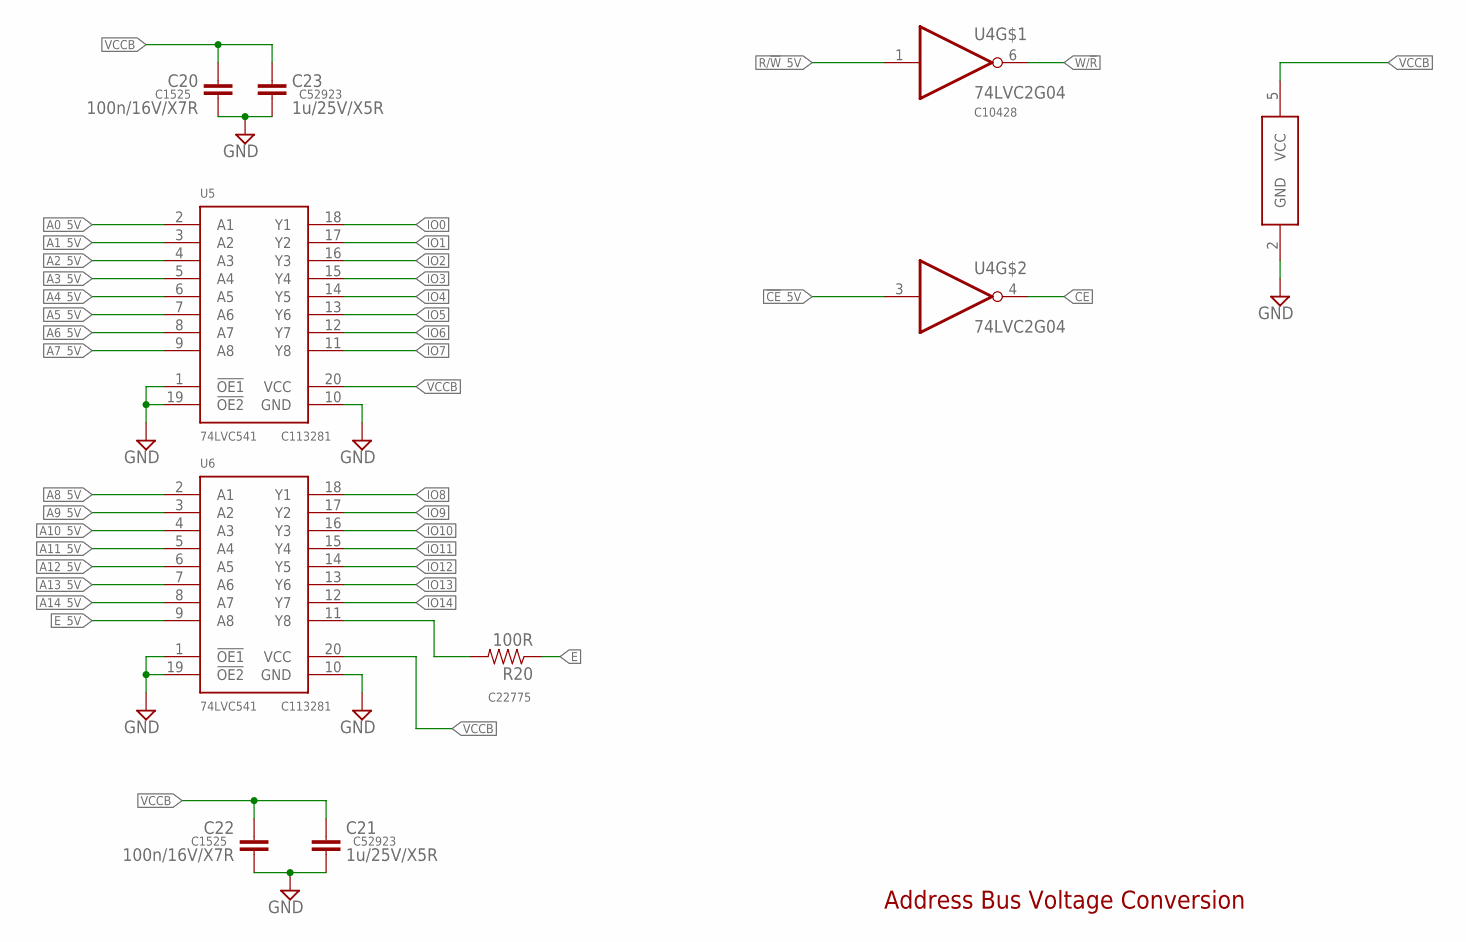
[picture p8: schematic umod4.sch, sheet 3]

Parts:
C20, C22: 100n/16V/X7R; 0402-CAP; LCSC_PART C1525
C21, C23: 1u/25V/X5R; 0402-CAP; LCSC_PART C52923
R20: 100R; 0603-RES; LCSC_PART C22775
U4: 74LVC2G04; SOT23-6; LCSC_PART C10428
U5, U6: 74LVC541; TSSOP-20; LCSC_PART C113281

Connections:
!CE!_5V: U4.3 (I); also elsewhere on the board
A0_5V: U5.2 (A1); also elsewhere on the board
A1_5V: U5.3 (A2); also elsewhere on the board
A2_5V: U5.4 (A3); also elsewhere on the board
A3_5V: U5.5 (A4); also elsewhere on the board
A4_5V: U5.6 (A5); also elsewhere on the board
A5_5V: U5.7 (A6); also elsewhere on the board
A6_5V: U5.8 (A7); also elsewhere on the board
A7_5V: U5.9 (A8); also elsewhere on the board
A8_5V: U6.2 (A1); also elsewhere on the board
A9_5V: U6.3 (A2); also elsewhere on the board
A10_5V: U6.4 (A3); also elsewhere on the board
A11_5V: U6.5 (A4); also elsewhere on the board
A12_5V: U6.6 (A5); also elsewhere on the board
A13_5V: U6.7 (A6); also elsewhere on the board
A14_5V: U6.8 (A7); also elsewhere on the board
CE: U4.4 (O); also elsewhere on the board
E: R20.1; also elsewhere on the board
E_5V: U6.9 (A8); also elsewhere on the board
GND: C20.2, C21.2, C22.2, C23.2, U4.2 (GND), U5.1 (!OE1), U5.10 (GND), U5.19 (!OE2), U6.1 (!OE1), U6.10 (GND), U6.19 (!OE2); also elsewhere on the board
IO0: U5.18 (Y1); also elsewhere on the board
IO1: U5.17 (Y2); also elsewhere on the board
IO2: U5.16 (Y3); also elsewhere on the board
IO3: U5.15 (Y4); also elsewhere on the board
IO4: U5.14 (Y5); also elsewhere on the board
IO5: U5.13 (Y6); also elsewhere on the board
IO6: U5.12 (Y7); also elsewhere on the board
IO7: U5.11 (Y8); also elsewhere on the board
IO8: U6.18 (Y1); also elsewhere on the board
IO9: U6.17 (Y2); also elsewhere on the board
IO10: U6.16 (Y3); also elsewhere on the board
IO11: U6.15 (Y4); also elsewhere on the board
IO12: U6.14 (Y5); also elsewhere on the board
IO13: U6.13 (Y6); also elsewhere on the board
IO14: U6.12 (Y7); also elsewhere on the board
unnamed: R20.2, U6.11 (Y8)
R/!W!_5V: U4.1 (I); also elsewhere on the board
VCCB: C20.1, C21.1, C22.1, C23.1, U4.5 (VCC), U5.20 (VCC), U6.20 (VCC); also elsewhere on the board
W/!R!: U4.6 (O); also elsewhere on the board

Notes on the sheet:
Address Bus Voltage Conversion

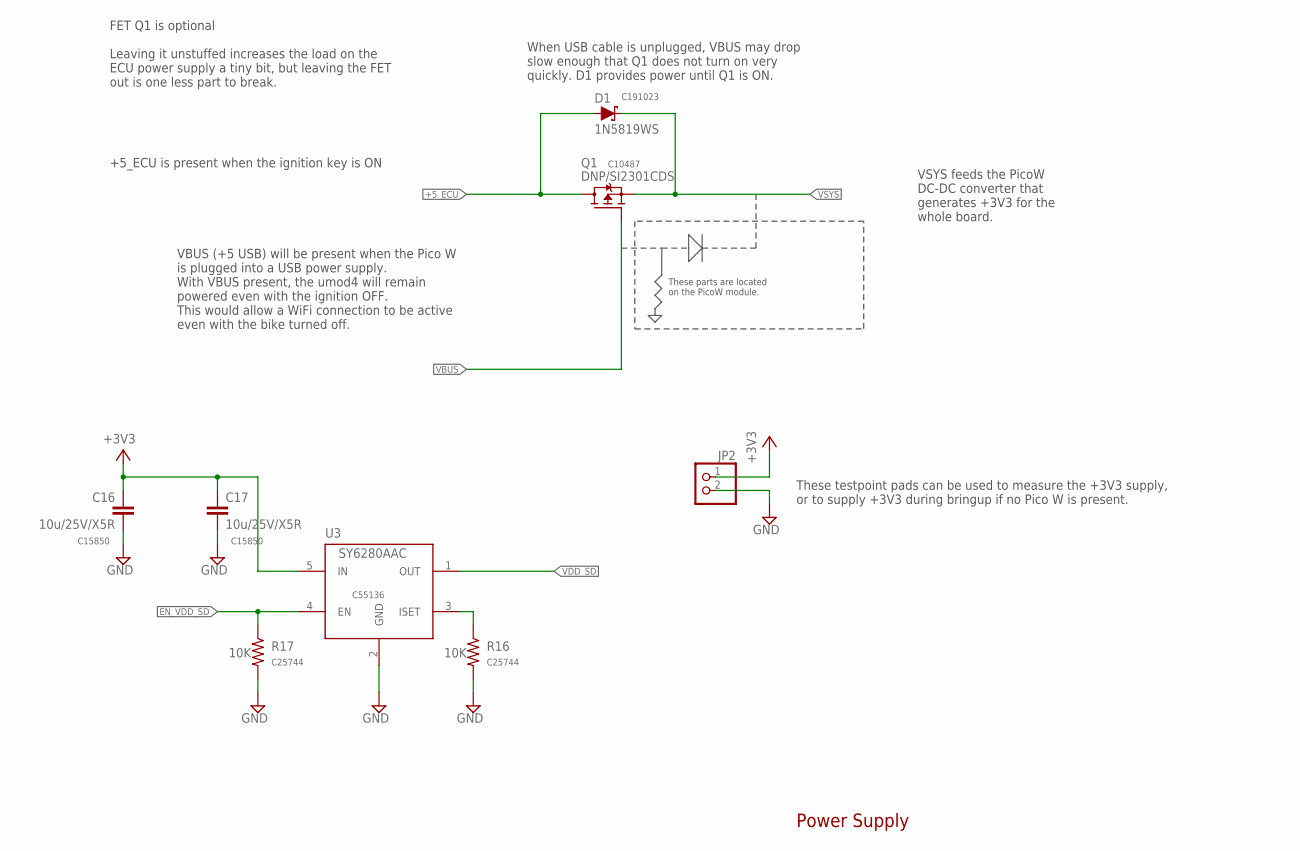
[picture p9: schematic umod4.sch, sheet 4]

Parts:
C16, C17: 10u/25V/X5R; SMD-0805; LCSC_PART C15850
D1: 1N5819WS; SOD-323; LCSC_PART C191023
JP2: PINHD-1X2; 1X02
Q1: DNP/SI2301CDS; SOT23
R16, R17: 10K; 0402-RES; LCSC_PART C25744
U3: SY6280AAC; SOT23-5; LCSC_PART C55136

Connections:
+3V3: C16.1, C17.1, JP2.1, U3.5 (IN); also elsewhere on the board
+5_ECU: D1.A, Q1.D; also elsewhere on the board
EN_VDD_SD: R17.1, U3.4 (EN); also elsewhere on the board
GND: C16.2, C17.2, JP2.2, R16.2, R17.2, U3.2 (GND); also elsewhere on the board
unnamed: R16.1, U3.3 (ISET)
VBUS: Q1.G; also elsewhere on the board
VDD_SD: U3.1 (OUT); also elsewhere on the board
VSYS: D1.C, Q1.S; also elsewhere on the board

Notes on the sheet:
Power Supply
VSYS feeds the PicoW DC-DC converter that generates +3V3 for the whole board.
These parts are located on the PicoW module.
These testpoint pads can be used to measure the +3V3 supply, or to supply +3V3 during bringup if no Pico W is present.
When USB cable is unplugged, VBUS may drop slow enough that Q1 does not turn on very quickly. D1 provides power until Q1 is ON.
+5_ECU is present when the ignition key is ON
VBUS (+5 USB) will be present when the Pico W is plugged into a USB power supply. With VBUS present, the umod4 will remain powered even with the ignition OFF. This would allow a WiFi connection to be active even with the bike turned off.
FET Q1 is optional Leaving it unstuffed increases the load on the ECU power supply a tiny bit, but leaving the FET out is one less part to break.

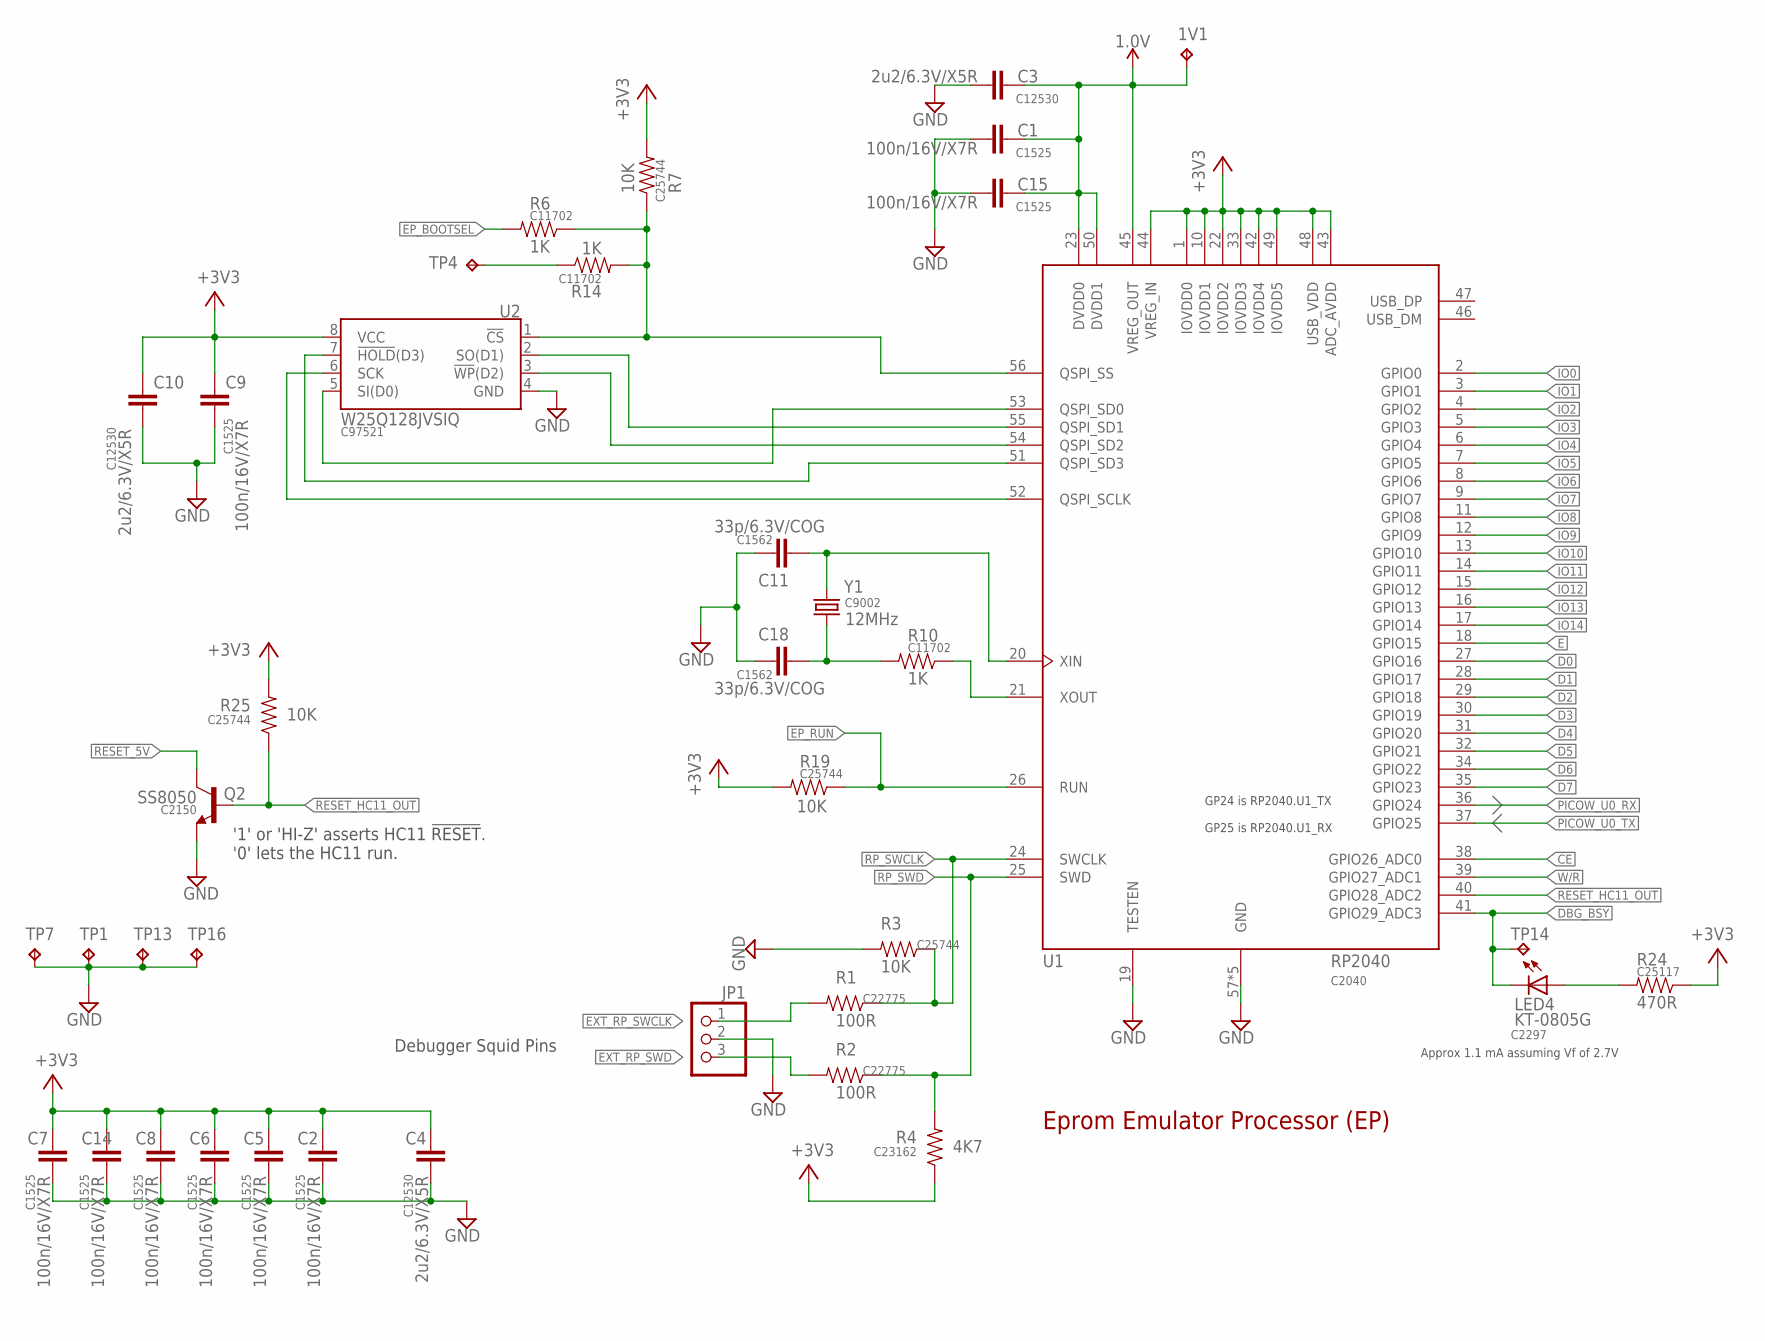
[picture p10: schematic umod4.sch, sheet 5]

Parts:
1V1: TPB1,27; B1,27
C1, C2, C5, C6, C7, C8, C9, C14, C15: 100n/16V/X7R; 0402-CAP; LCSC_PART C1525
C3, C4, C10: 2u2/6.3V/X5R; 0402-CAP; LCSC_PART C12530
C11, C18: 33p/6.3V/COG; 0402-CAP; LCSC_PART C1562
JP1: PINHD-1X3; 1X03
LED4: KT-0805G; SML0805; LCSC_PART C2297
Q2: SS8050; SOT23-3; LCSC_PART C2150
R1, R2: 100R; 0603-RES; LCSC_PART C22775
R3, R7, R19, R25: 10K; 0402-RES; LCSC_PART C25744
R4: 4K7; 0603-RES; LCSC_PART C23162
R6, R10, R14: 1K; 0402-RES; LCSC_PART C11702
R24: 470R; 0402-RES; LCSC_PART C25117
TP1, TP4, TP7, TP13, TP14, TP16: 1035; KEYSTONE-1035
U1: RP2040; RP2040-QFN56; LCSC_PART C2040
U2: W25Q128JVSIQ; SOIC-8; LCSC_PART C97521
Y1: 12MHz; CRYSTAL-SMD-3.2X2.5MM; LCSC_PART C9002

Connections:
1.0V: 1V1.TP, C1.1, C3.1, C15.1, U1.23 (DVDD0), U1.45 (VREG_OUT), U1.50 (DVDD1)
!RESET!_5V: Q2.3 (C); also elsewhere on the board
!RESET!_HC11_OUT: Q2.1 (B), R25.1, U1.40 (GPIO28_ADC2)
+3V3: C2.1, C4.1, C5.1, C6.1, C7.1, C8.1, C9.1, C10.1, C14.1, R4.1, R7.2, R19.2, R24.1, R25.2, U1.1 (IOVDD0), U1.10 (IOVDD1), U1.22 (IOVDD2), U1.33 (IOVDD3), U1.42 (IOVDD4), U1.43 (ADC_AVDD), U1.44 (VREG_IN), U1.48 (USB_VDD), U1.49 (IOVDD5), U2.8 (VCC); also elsewhere on the board
CE: U1.38 (GPIO26_ADC0); also elsewhere on the board
D0: U1.27 (GPIO16); also elsewhere on the board
D1: U1.28 (GPIO17); also elsewhere on the board
D2: U1.29 (GPIO18); also elsewhere on the board
D3: U1.30 (GPIO19); also elsewhere on the board
D4: U1.31 (GPIO20); also elsewhere on the board
D5: U1.32 (GPIO21); also elsewhere on the board
D6: U1.34 (GPIO22); also elsewhere on the board
D7: U1.35 (GPIO23); also elsewhere on the board
DBG_BSY: LED4.C, TP14.P$1, U1.41 (GPIO29_ADC3)
E: U1.18 (GPIO15); also elsewhere on the board
EP_BOOTSEL: R6.2; also elsewhere on the board
EP_RUN: R19.1, U1.26 (RUN); also elsewhere on the board
EXT_RP_SWCLK: JP1.1, R1.2
EXT_RP_SWD: JP1.3, R2.2
GND: C1.2, C2.2, C3.2, C4.2, C5.2, C6.2, C7.2, C8.2, C9.2, C10.2, C11.1, C14.2, C15.2, C18.1, JP1.2, Q2.2 (E), R3.2, TP1.P$1, TP7.P$1, TP13.P$1, TP16.P$1, U1.19 (TESTEN), U1.57 (GND), U1.GND@1 (GND), U1.GND@2 (GND), U1.GND@3 (GND), U1.GND@4 (GND), U2.4 (GND); also elsewhere on the board
IO0: U1.2 (GPIO0); also elsewhere on the board
IO1: U1.3 (GPIO1); also elsewhere on the board
IO2: U1.4 (GPIO2); also elsewhere on the board
IO3: U1.5 (GPIO3); also elsewhere on the board
IO4: U1.6 (GPIO4); also elsewhere on the board
IO5: U1.7 (GPIO5); also elsewhere on the board
IO6: U1.8 (GPIO6); also elsewhere on the board
IO7: U1.9 (GPIO7); also elsewhere on the board
IO8: U1.11 (GPIO8); also elsewhere on the board
IO9: U1.12 (GPIO9); also elsewhere on the board
IO10: U1.13 (GPIO10); also elsewhere on the board
IO11: U1.14 (GPIO11); also elsewhere on the board
IO12: U1.15 (GPIO12); also elsewhere on the board
IO13: U1.16 (GPIO13); also elsewhere on the board
IO14: U1.17 (GPIO14); also elsewhere on the board
unnamed: C18.2, R10.2, Y1.1
unnamed: C11.2, U1.20 (XIN), Y1.3 (2)
unnamed: R14.1, TP4.P$1
unnamed: R10.1, U1.21 (XOUT)
unnamed: LED4.A, R24.2
unnamed: R6.1, R7.1, R14.2, U1.56 (QSPI_SS), U2.1 (!CS!)
unnamed: U1.52 (QSPI_SCLK), U2.6 (SCK)
unnamed: U1.53 (QSPI_SD0), U2.5 (SI(D0))
unnamed: U1.55 (QSPI_SD1), U2.2 (SO(D1))
unnamed: U1.54 (QSPI_SD2), U2.3 (!WP!(D2))
unnamed: U1.51 (QSPI_SD3), U2.7 (!HOLD!(D3))
PICOW_U0_RX: U1.36 (GPIO24); also elsewhere on the board
PICOW_U0_TX: U1.37 (GPIO25); also elsewhere on the board
RP_SWCLK: R1.1, R3.1, U1.24 (SWCLK); also elsewhere on the board
RP_SWD: R2.1, R4.2, U1.25 (SWD); also elsewhere on the board
W/!R!: U1.39 (GPIO27_ADC1); also elsewhere on the board

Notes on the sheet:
Eprom Emulator Processor (EP)
Approx 1.1 mA assuming Vf of 2.7V
GP24 is RP2040.U1_TX
GP25 is RP2040.U1_RX
'1' or 'HI-Z' asserts HC11 !RESET!. '0' lets the HC11 run.
Debugger Squid Pins

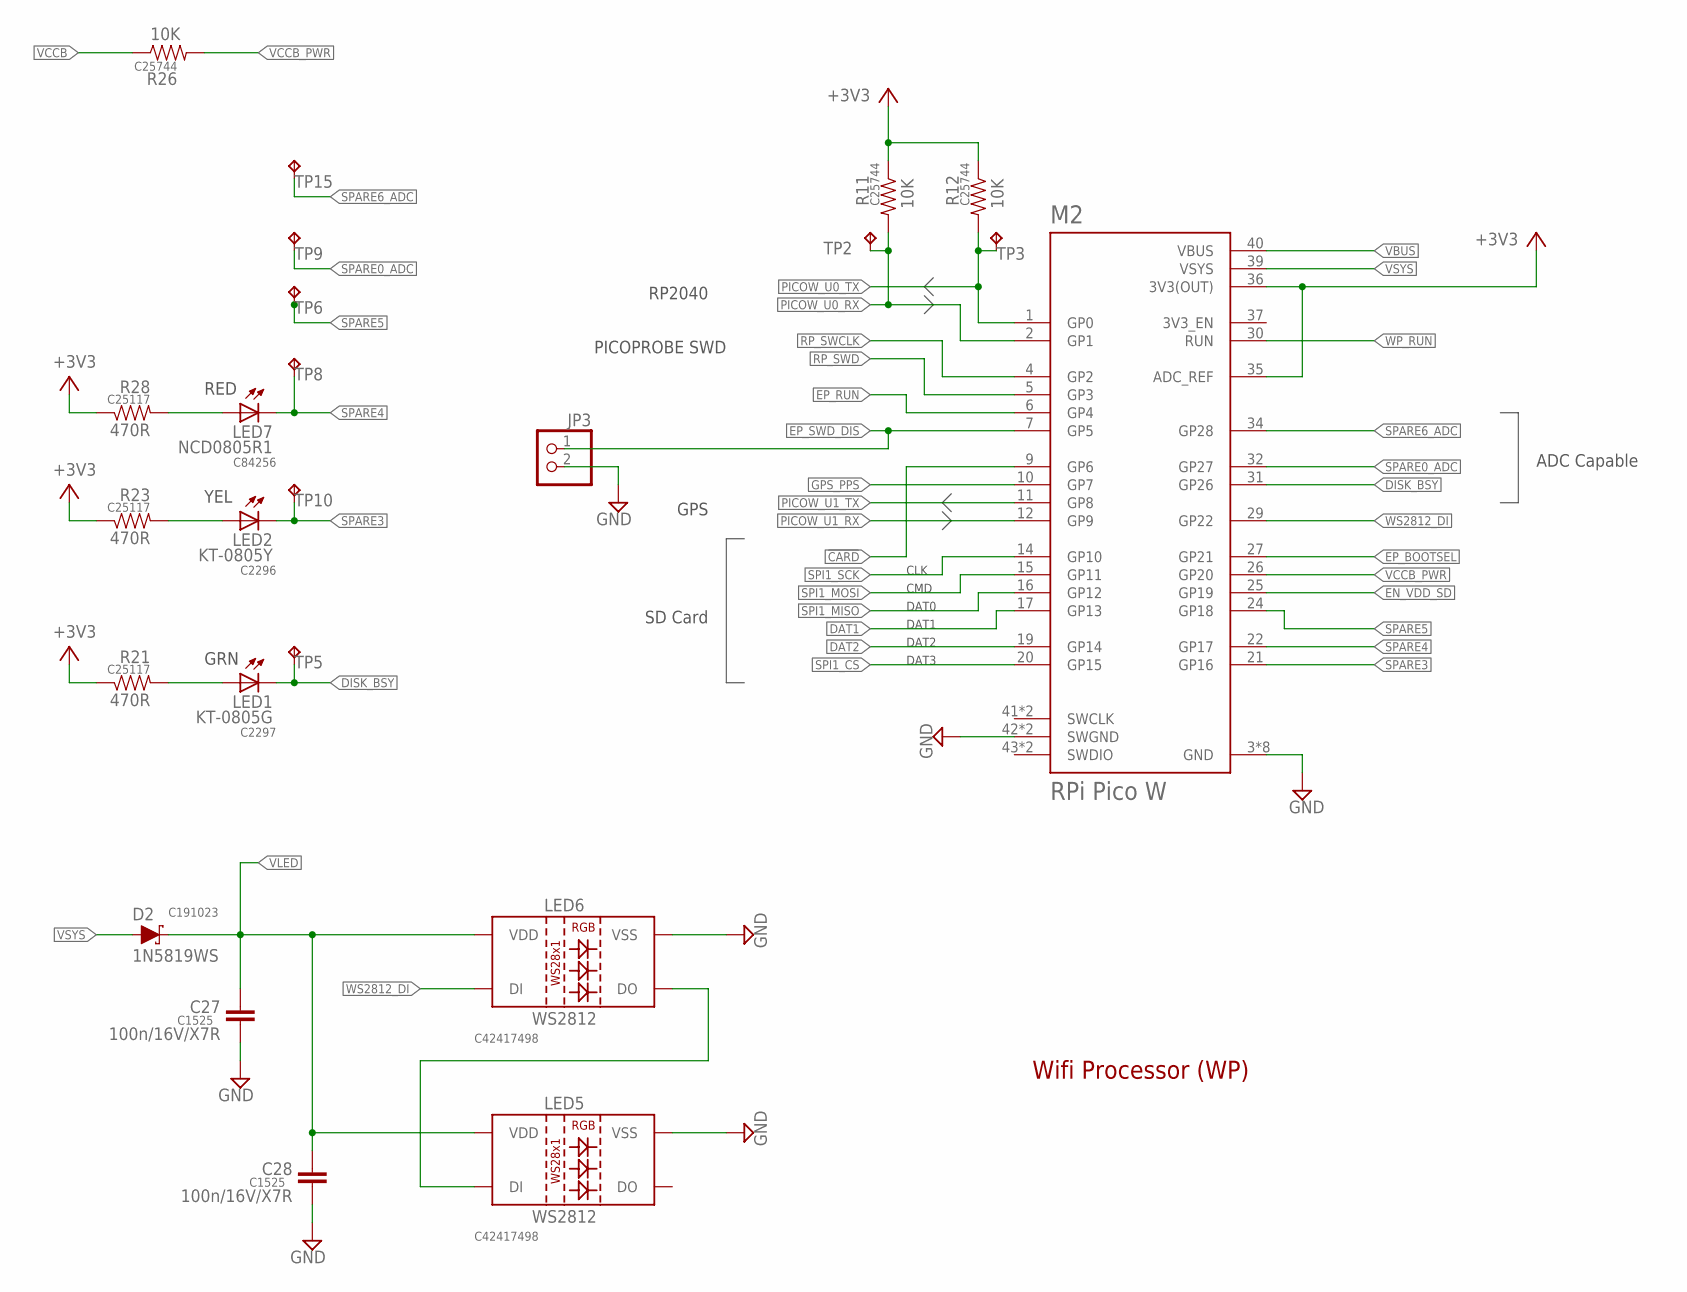
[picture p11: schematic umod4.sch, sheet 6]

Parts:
C27, C28: 100n/16V/X7R; 0402-CAP; LCSC_PART C1525
D2: 1N5819WS; SOD-323; LCSC_PART C191023
JP3: PINHD-1X2; 1X02
LED1: KT-0805G; SML0805; LCSC_PART C2297
LED2: KT-0805Y; SML0805; LCSC_PART C2296
LED5, LED6: WS2812; WS2812B; LCSC_PART C42417498
LED7: NCD0805R1; SML0805; LCSC_PART C84256
M2: RPi Pico W; PICO-TH
R11, R12, R26: 10K; 0402-RES; LCSC_PART C25744
R21, R23, R28: 470R; 0402-RES; LCSC_PART C25117
TP2, TP3, TP5, TP6, TP8, TP9, TP10, TP15: 1035; KEYSTONE-1035

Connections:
!CARD: M2.9 (GP6); also elsewhere on the board
+3V3: M2.35 (ADC_REF), M2.36 (3V3(OUT)), R11.1, R12.1, R21.1, R23.1, R28.1; also elsewhere on the board
DAT1: M2.17 (GP13); also elsewhere on the board
DAT2: M2.19 (GP14); also elsewhere on the board
DISK_BSY: LED1.C, M2.31 (GP26), TP5.P$1
EN_VDD_SD: M2.25 (GP19); also elsewhere on the board
EP_BOOTSEL: M2.27 (GP21); also elsewhere on the board
EP_RUN: M2.6 (GP4); also elsewhere on the board
EP_SWD_DIS: JP3.1, M2.7 (GP5)
GND: C27.2, C28.2, JP3.2, LED5.3 (VSS), LED6.3 (VSS), M2.3 (GND), M2.8 (GND), M2.13 (GND), M2.18 (GND), M2.23 (GND), M2.28 (GND), M2.33 (GND), M2.38 (GND), M2.42 (SWGND), M2.45 (SWGND); also elsewhere on the board
GPS_PPS: M2.10 (GP7); also elsewhere on the board
unnamed: LED2.A, R23.2
unnamed: LED5.4 (DI), LED6.2 (DO)
unnamed: LED1.A, R21.2
unnamed: LED7.A, R28.2
PICOW_U0_RX: M2.2 (GP1), R11.2, TP2.P$1; also elsewhere on the board
PICOW_U0_TX: M2.1 (GP0), R12.2, TP3.P$1; also elsewhere on the board
PICOW_U1_RX: M2.12 (GP9); also elsewhere on the board
PICOW_U1_TX: M2.11 (GP8); also elsewhere on the board
RP_SWCLK: M2.4 (GP2); also elsewhere on the board
RP_SWD: M2.5 (GP3); also elsewhere on the board
SPARE0_ADC: M2.32 (GP27), TP9.P$1
SPARE3: LED2.C, M2.21 (GP16), TP10.P$1
SPARE4: LED7.C, M2.22 (GP17), TP8.P$1
SPARE5: M2.24 (GP18), TP6.P$1
SPARE6_ADC: M2.34 (GP28), TP15.P$1
SPI1_CS: M2.20 (GP15); also elsewhere on the board
SPI1_MISO: M2.16 (GP12); also elsewhere on the board
SPI1_MOSI: M2.15 (GP11); also elsewhere on the board
SPI1_SCK: M2.14 (GP10); also elsewhere on the board
VBUS: M2.40 (VBUS); also elsewhere on the board
VCCB: R26.1; also elsewhere on the board
VCCB_PWR: M2.26 (GP20), R26.2
VLED: C27.1, C28.1, D2.C, LED5.1 (VDD), LED6.1 (VDD)
VSYS: D2.A, M2.39 (VSYS); also elsewhere on the board
WP_RUN: M2.30 (RUN)
WS2812_DI: LED6.4 (DI), M2.29 (GP22)

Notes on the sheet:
Wifi Processor (WP)
GPS
PICOPROBE SWD
RP2040
SD Card
DAT0
DAT1
DAT2
DAT3
CMD
CLK
ADC Capable
RED
YEL
GRN

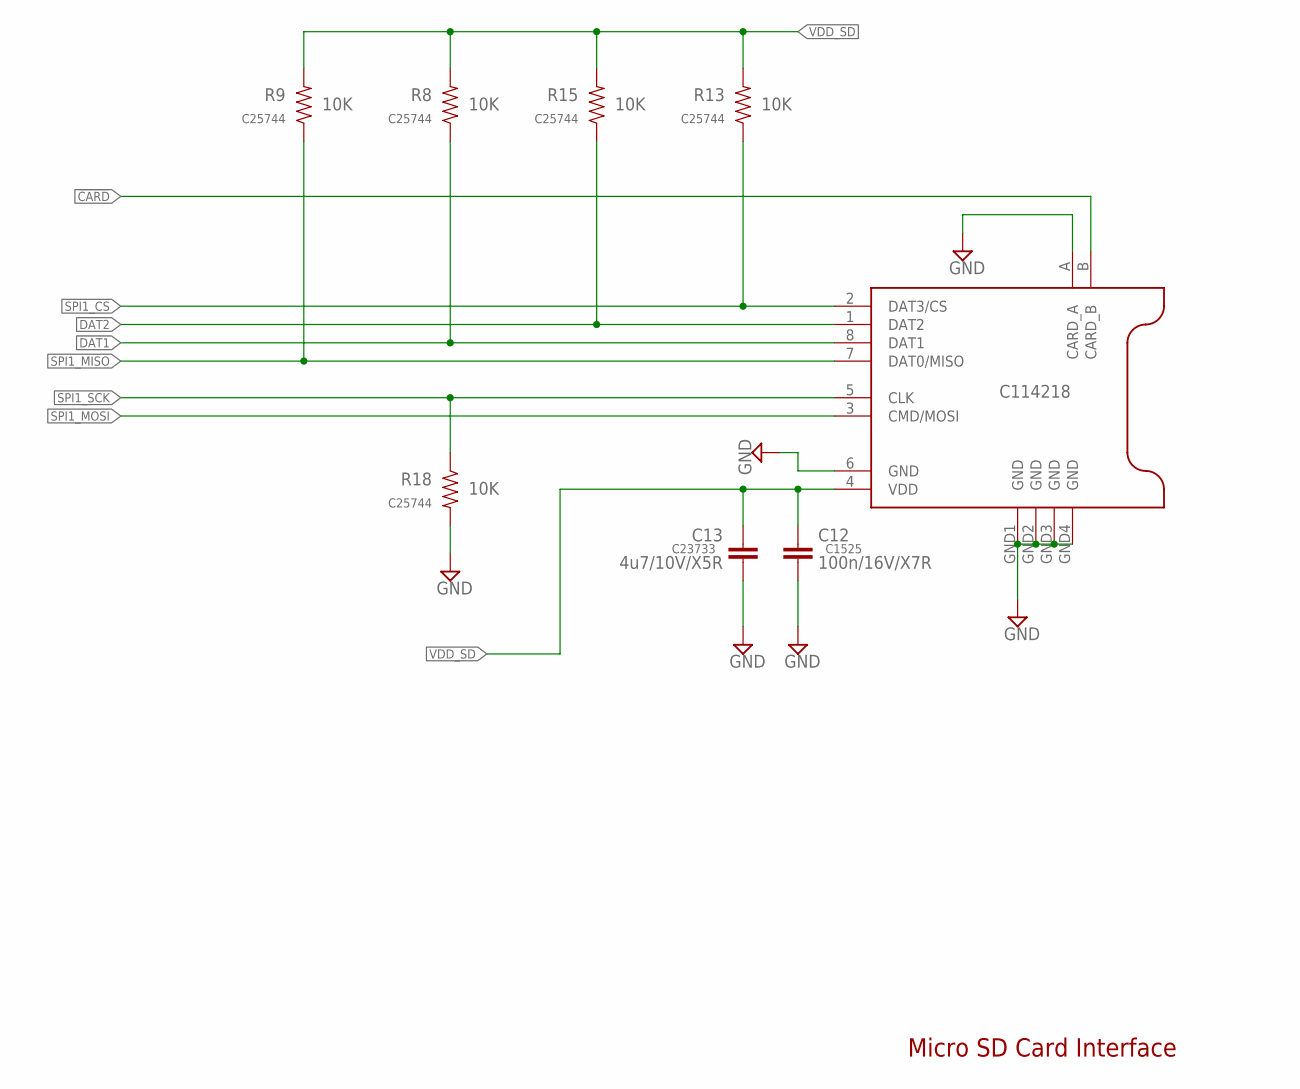
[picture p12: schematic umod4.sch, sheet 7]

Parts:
C12: 100n/16V/X7R; 0402-CAP; LCSC_PART C1525
C13: 4u7/10V/X5R; 0402-CAP; LCSC_PART C23733
R8, R9, R13, R15, R18: 10K; 0402-RES; LCSC_PART C25744
SD1: DM3AT-SF-PEJM5; DM3AT; LCSC_PART C114218

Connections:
!CARD: SD1.B (CARD_B); also elsewhere on the board
DAT1: R8.1, SD1.8 (DAT1); also elsewhere on the board
DAT2: R15.1, SD1.1 (DAT2); also elsewhere on the board
GND: C12.2, C13.2, R18.2, SD1.6 (GND), SD1.A (CARD_A), SD1.GND1 (GND), SD1.GND2 (GND), SD1.GND3 (GND), SD1.GND4 (GND); also elsewhere on the board
SPI1_CS: R13.1, SD1.2 (DAT3/CS); also elsewhere on the board
SPI1_MISO: R9.1, SD1.7 (DAT0/MISO); also elsewhere on the board
SPI1_MOSI: SD1.3 (CMD/MOSI); also elsewhere on the board
SPI1_SCK: R18.1, SD1.5 (CLK); also elsewhere on the board
VDD_SD: C12.1, C13.1, R8.2, R9.2, R13.2, R15.2, SD1.4 (VDD); also elsewhere on the board

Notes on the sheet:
Micro SD Card Interface

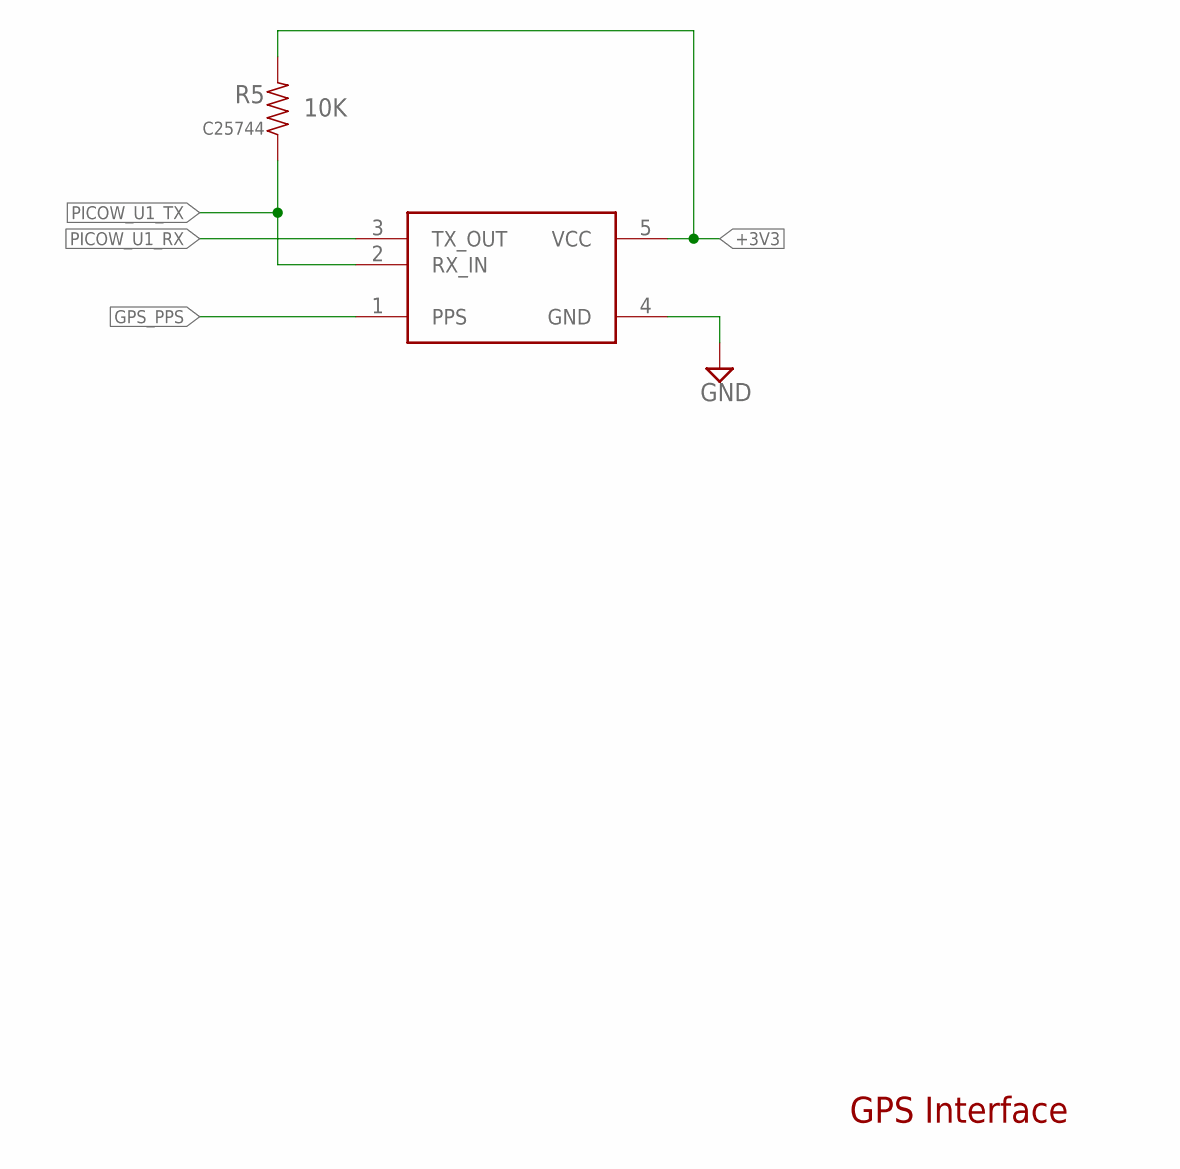
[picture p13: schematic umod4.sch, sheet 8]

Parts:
M1: Generic single-sided NEO-8; GPS-MODULE-DS
R5: 10K; 0402-RES; LCSC_PART C25744

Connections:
+3V3: M1.5 (VCC), R5.2; also elsewhere on the board
GND: M1.4 (GND); also elsewhere on the board
GPS_PPS: M1.1 (PPS); also elsewhere on the board
PICOW_U1_RX: M1.3 (TX_OUT); also elsewhere on the board
PICOW_U1_TX: M1.2 (RX_IN), R5.1; also elsewhere on the board

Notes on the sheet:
GPS Interface

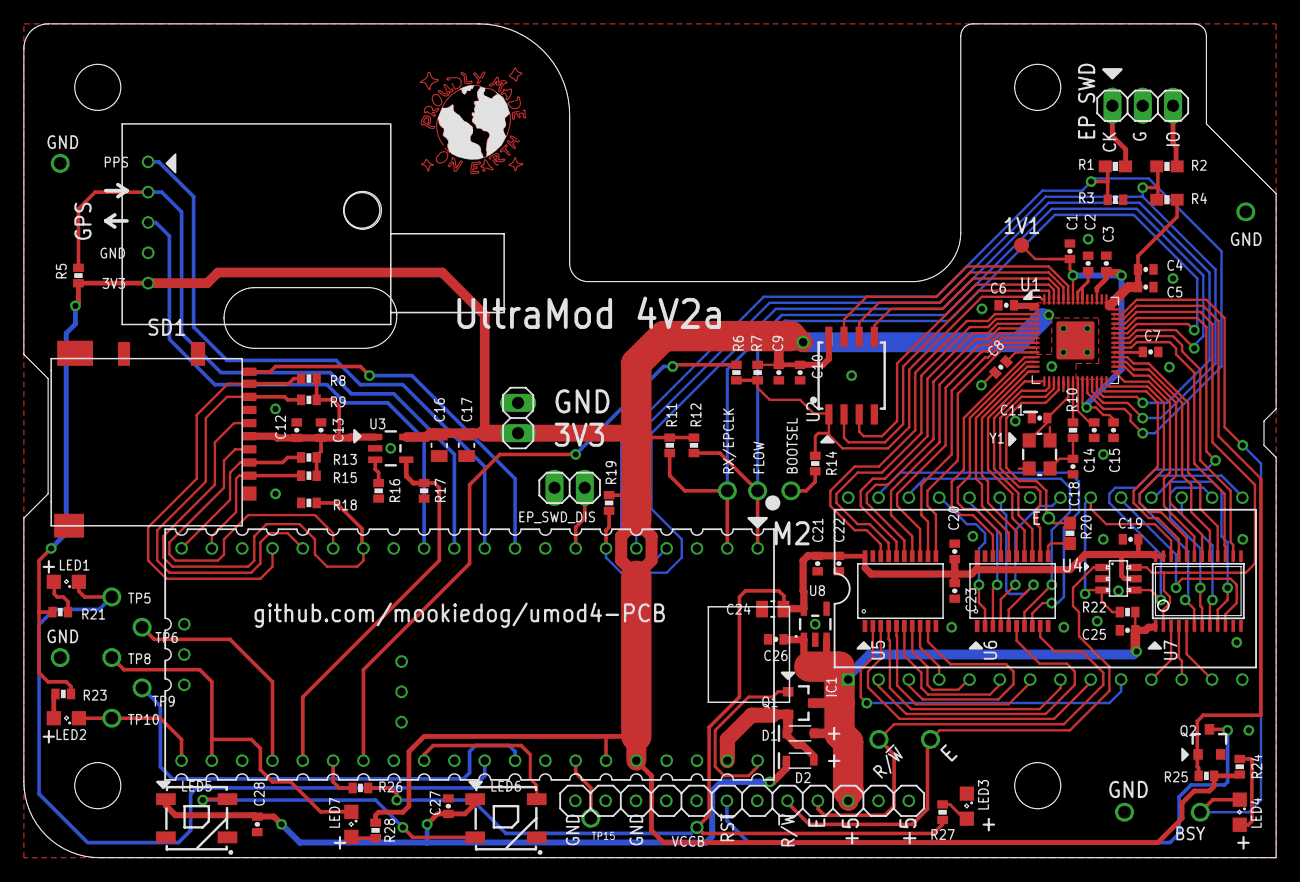
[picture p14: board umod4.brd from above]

Board: 2 copper layers, 104.9 x 69.8 mm, 101 parts (0 on the bottom side), 110 nets.

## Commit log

2023-03-04 Updates to README, Changelist, and design
    [umod4.brd, umod4.sch]
2023-03-25 New: 10-pin SWD, WS2812-2020, TestPlan doc
    [umod4.brd, umod4.sch]
2023-03-26 Added WP squid pins
    [umod4.brd, umod4.sch]
2023-03-26 Added thoughts on unswitched power supply
2023-04-02 Pullup Stops GPS From Disabling Its UART
    [umod4.brd, umod4.sch]
2023-05-08 Latest updates. See ChangeList.md.
    [umod4.brd, umod4.sch]
2023-05-14 Power supply design updates
    [umod4.brd, umod4.sch]
2023-05-17 Removed SD power switch
    [umod4.brd, umod4.sch]
2023-05-20 Before rotating SPI connector
    [umod4.brd, umod4.sch]
2023-05-21 Flipped J5 for easier hand soldering
    [umod4.brd]
2023-05-24 Updated all LSCS part attributes
    [umod4.brd, umod4.sch]
2023-05-24 More updates to add LCSC part numbers
    [umod4.brd, umod4.sch]
2023-05-31 Before renumbering components
    [umod4.brd, umod4.sch]
2023-06-03 PCB Updates as per ChangeList.md
    [umod4.brd, umod4.sch]
2023-06-18 Latest changes after github token changed
    [umod4.brd, umod4.sch]
2024-12-29 remove file with wrong case in name
2024-12-29 Fix filename case
2024-12-30 Updated debugger connections for WP, EP
    [umod4.brd, umod4.sch]
2025-01-03 Power Supply Simplification
    [umod4.brd, umod4.sch]
2025-01-04 Update current status in README
2025-01-07 All changes up to 4V1a fabrication
    [umod4.brd, umod4.sch]
2025-05-17 Update changelist with potential approach for WS2812 EP status LED
2026-04-06 Updates for 4V2 work-in-progress
    - Latest version of 4V2 incorporating changes as per Changelist-4V2.md
    [umod4.brd, umod4.sch]
2026-07-04 4v2a Release: add caps, DNP convention, production automation
    Board changes:
    - See Changelist-4V2.md for details
    Tooling:
    - Add preproduction.py: BOM generation (HTML + CSV), CPL generation via Eagle ULP batch mode, gerber freshness check, and ZIP packaging
    - Add jlcpcb_smta_exporter_v7.ulp: modified to accept batch-mode arguments, bypassing interactive dialogs when invoked from script
    - Update jlcpcb_2_layer_v72.cam: output path changed to build/cam/
    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
    [umod4.brd, umod4.sch]
2026-07-16 Close out 4V2: bring-up test plan, ordering notes, gitignore tweak
    - Add TestPlan-4V2.md, the bench bring-up checklist for boards back from JLCPCB.
    - For WS2812: JLCPCB would seem to prefer polarity markings (+ for VCC/- for GND) instead of a pin1 indicator
    - fixed .gitignore's __*/ pattern to __* so it matches files, not just dirs

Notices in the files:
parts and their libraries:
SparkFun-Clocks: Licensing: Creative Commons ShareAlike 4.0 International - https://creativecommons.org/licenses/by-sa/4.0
